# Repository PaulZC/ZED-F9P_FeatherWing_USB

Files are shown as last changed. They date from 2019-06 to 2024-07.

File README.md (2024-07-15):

# ZED-F9P FeatherWing USB

A GNSS FeatherWing incorporating the dual-band (L1 + L2) [u-blox ZED-F9P](https://www.u-blox.com/en/product/zed-f9p-module)

The board can be used stand-alone, powered and interfaced through the USB connector:

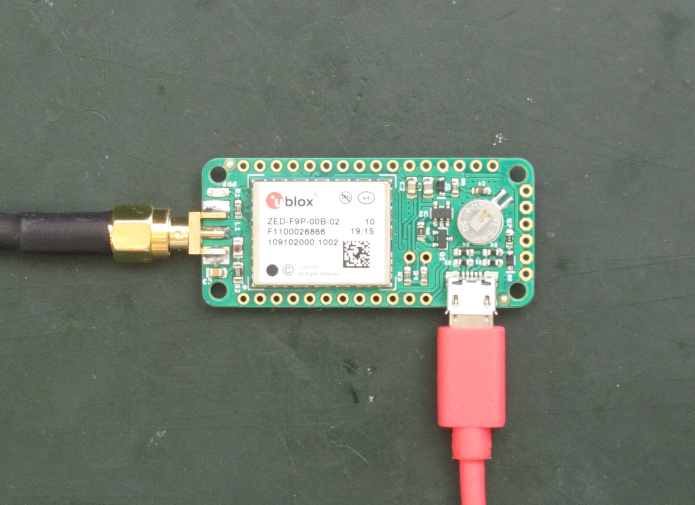
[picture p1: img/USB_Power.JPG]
USB_Power


However, it is designed to mount on top of the [Adafruit Feather M0 Adalogger](https://www.adafruit.com/products/2796)
to form a very compact dual-band PPK data logger or RTK system:

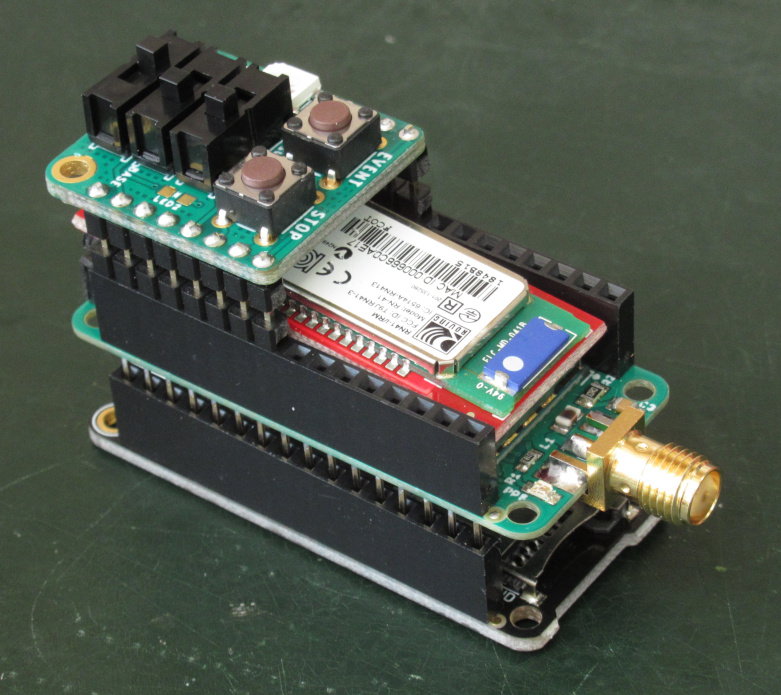
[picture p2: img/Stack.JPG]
Stack


This version provides access to the ZED-F9P's USB port. The [ZED-F9P_FeatherWing](https://github.com/PaulZC/ZED-F9P_FeatherWing) is a simpler version
with fewer components and a CR1220 back-up battery but without USB.

Based extensively on the [Adafruit Ultimate GPS FeatherWing](https://www.adafruit.com/product/3133) and the
[SparkFun GPS-RTK2 Board](https://www.sparkfun.com/products/15136)

If you don't want to make your own FeatherWing and want to use the SparkFun GPS-RTK2 Board instead, you can find a tutorial showing you how to do that
[here](https://github.com/PaulZC/F9P_RAWX_Logger)

See [LEARN.md](./LEARN.md) for more details

[ASSEMBLY.md](./ASSEMBLY.md) contains instructions on how to assemble the PCB

[PAIRING.md](./PAIRING.md) contains instructions on how to configure two SparkFun Bluetooth Mate Gold boards
as a bonded pair, to provide a 115200 Baud RTCM link

The Eagle files are available in the [Eagle folder](./Eagle)

The schematic is available [here](./Schematic.PNG)

The BOM is available [here](./BOM.pdf)

The PCB thickness should be 0.8mm: see the microstrip calculations on the [SparkFun schematic](https://cdn.sparkfun.com/assets/9/a/0/0/a/Qwiic_GPS-RTK2_-_ublox_ZED-F9P.pdf)

## Arduino Code

Two versions of the Arduino code can be found in the [Arduino folder](./Arduino):

- **RAWX_Logger_F9P** is very similar to the logger I wrote for the [NEO-M8T FeatherWing](https://github.com/PaulZC/NEO-M8T_GNSS_FeatherWing) but is substantially updated for the ZED-F9P. It does all of the message configuration via UART1. **PLEASE NOTE:** this example is out-of-date as it uses the old version of the SparkFun u-blox Library.

- **RAWX_Logger_F9P_I2C** uses **version 3.1.5** of the SparkFun u-blox GNSS library to do all of the message configuration via the I2C port instead of UART1. This makes
the code more efficient as it does not need to ignore the UBX ACK messages (on UART1) and can simply stream all data from UART1 to the SD card.

You can find instructions on how to install the Arduino IDE and the required libraries [here](https://github.com/PaulZC/F9P_RAWX_Logger/blob/master/SOFTWARE.md).

The code has three 'modes': Rover, Base and Survey_In. The mode is set via pins A0 and A3 by the [RAWX Logger Switches](https://github.com/PaulZC/RAWX_Logger_Switches). The RAWX
messages are logged to SD card in all three modes for post-processing with [rtklibexplorer's](https://rtklibexplorer.wordpress.com/) version of [RTKLIB](http://rtkexplorer.com/downloads/rtklib-code/).

You will find settings in the code to help with debugging should you need it. Uncomment the line which contains **#define DEBUG** to enable them.

## Updating the ZED-F9P firmware

u-blox released [version 1.12](https://www.u-blox.com/sites/default/files/UBX_F9_100_HPG_112_ZED_F9P.a26bfd58dfd11c233f8fdba6b99adc5a.bin) of the ZED-F9P firmware
on 12th July 2019. If you bought your device(s) before then, it would be beneficial to update. The update process is straight forward and can be done through
the Tools menu in [u-center](https://www.u-blox.com/en/product/u-center) **but the update can only be done through UART1. It will fail if you try to update through USB.**

The [Arduino folder](./Arduino) contains a sketch called ZED-F9P_Echo. This will turn the Adalogger into
a simple USB to UART pass-through which you can use to update the ZED-F9P using u-center. The code runs at **9600 Baud only** so you must tick the
_Use this baudrate for update_ box and select 9600 from the drop-down list. The advice on the u-blox portal seems to be to select the _Use chip erase_ option too.

Updating at 9600 Baud is very slow, but this is the only way to prevent Baud rate changes during the update. The Echo code is very simple and does not support
baud rate changes. If you want to update more quickly, you can use (e.g.) an FTDI TTL-232R-3V3 cable to connect to the UART1 pins instead of the Adalogger.

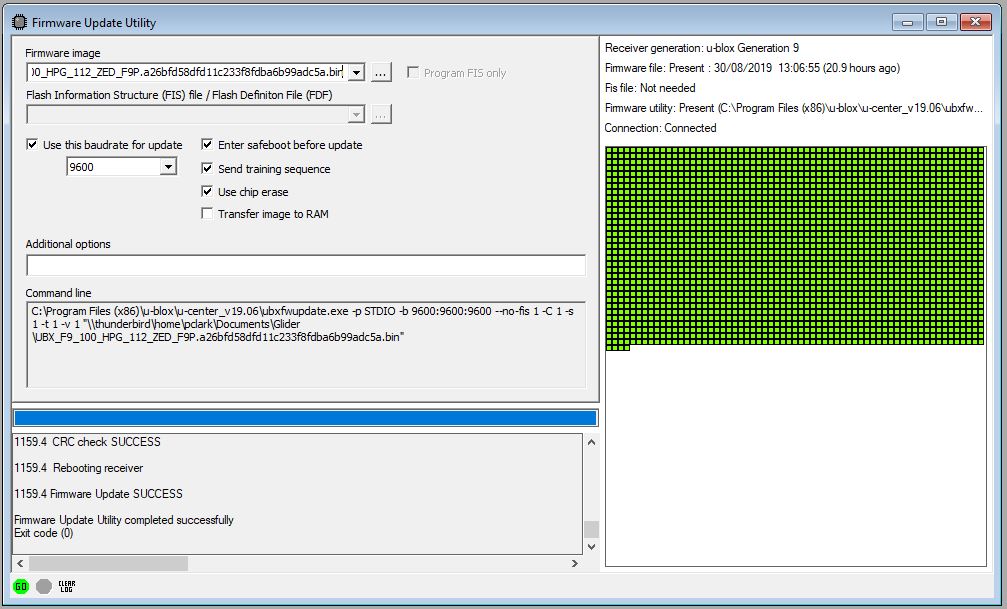
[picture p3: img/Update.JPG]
Update


## Acknowledgements

This project would not have been possible without the open source designs kindly provided by both Adafruit and SparkFun. Their work is gratefully acknowledged.

Adafruit invests time and resources providing this open source design, please support Adafruit and open-source hardware by purchasing products from Adafruit!

Feel like supporting open source hardware? Buy a board from SparkFun!

## Licence

Please see [LICENSE.md](./LICENSE.md) for details.

Enjoy!

**_Paul_**

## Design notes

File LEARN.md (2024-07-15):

# ZED-F9P FeatherWing USB: LEARN

Based extensively on the [Adafruit Ultimate GPS FeatherWing](https://www.adafruit.com/product/3133) and the
[SparkFun GPS-RTK2 Board](https://www.sparkfun.com/products/15136), the ZED-F9P FeatherWing USB takes all the great features of the GPS-RTK2 and squeezes them
into Adafruit FeatherWing format.

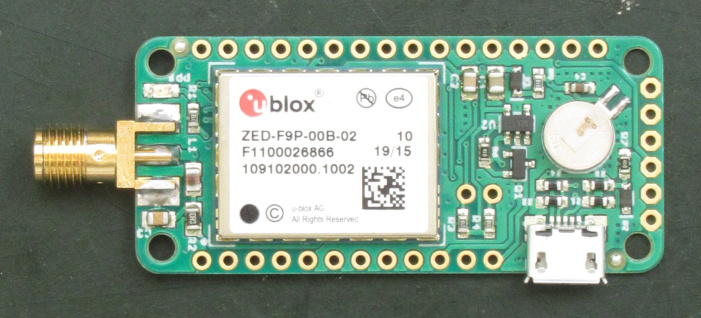
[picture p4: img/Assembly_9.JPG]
Assembly_9


The board can be used stand-alone, powered and interfaced through the USB connector:

USB_Power

However, it is designed to mount on top of the [Adafruit Feather M0 Adalogger](https://www.adafruit.com/products/2796)
to form a very compact dual-band PPK data logger or RTK system, especially when coupled with:
- A [SparkFun Bluetooth Mate Gold](https://www.sparkfun.com/products/12580) to provide the Real Time Correction Message link
- A [RAWX_Logger_Switches board](https://github.com/PaulZC/RAWX_Logger_Switches) to provide on/off, base/rover, survey_in, event and stop-logging buttons plus a NeoPixel for visual feedback

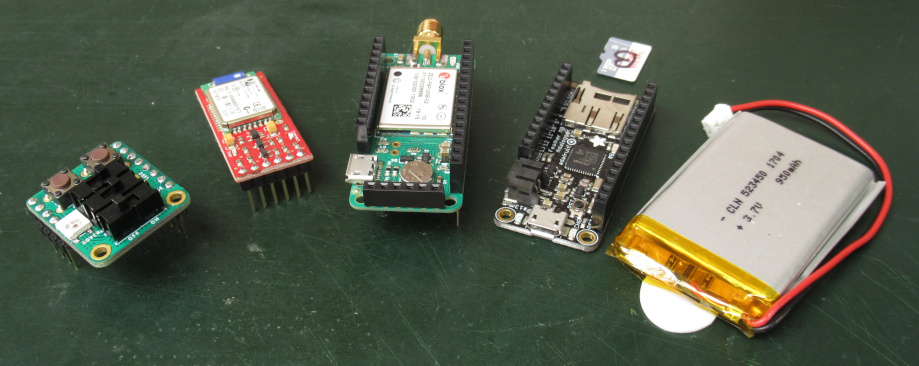
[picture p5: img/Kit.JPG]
Kit


Stack

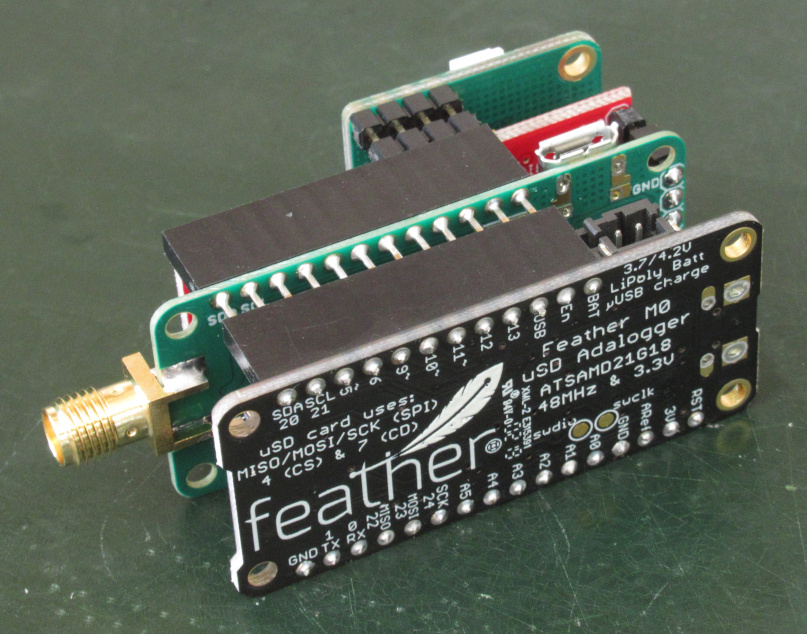
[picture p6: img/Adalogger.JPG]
Adalogger


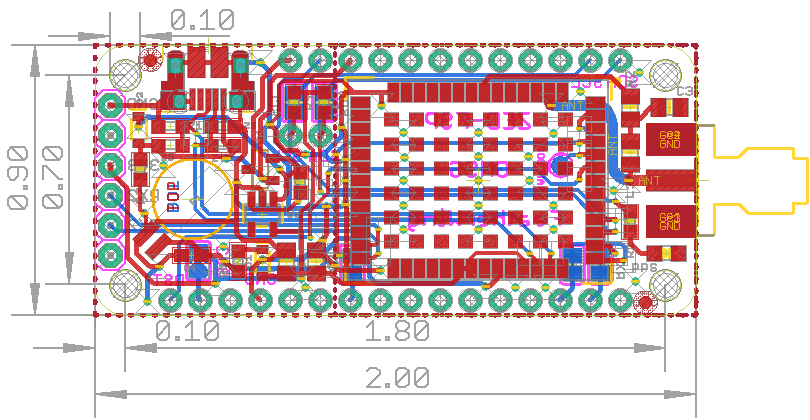
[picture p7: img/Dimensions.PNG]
Dimensions


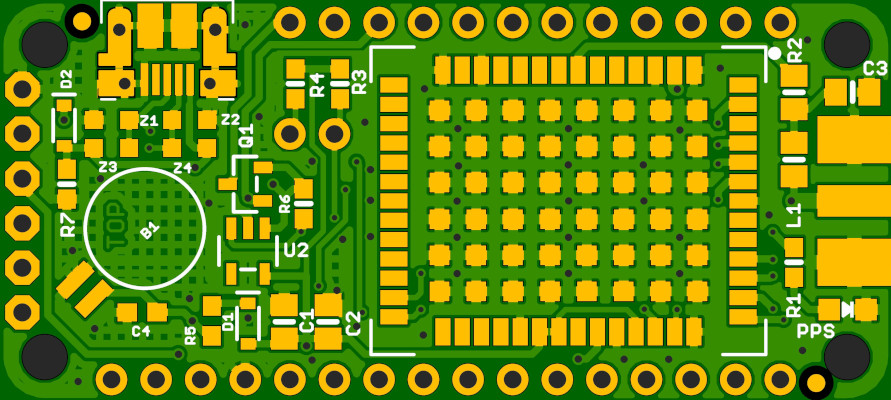
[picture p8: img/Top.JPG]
Top


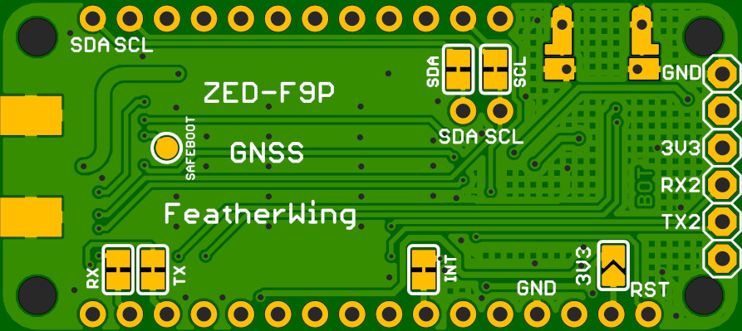
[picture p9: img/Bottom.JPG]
Bottom


### Power Options

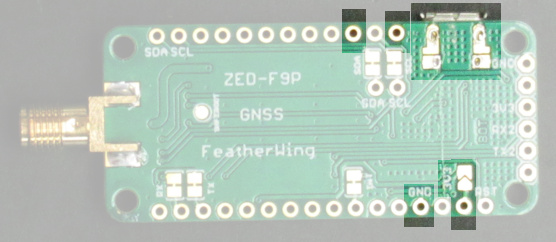
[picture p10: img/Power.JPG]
Power


The FeatherWing can be powered through:
- The micro-USB connector
- The standard FeatherWing LiPo battery and VBUS (USB) pins

The average current draw is approximately 140mA in Survey_In mode when powering the Adalogger, SparkFun Bluetooth Mate Gold and a Taoglas A.80.A.101111 antenna. Select your LiPo battery capacity accordingly!

The board has its own regulator which will regulate battery or USB power down to 3.3V.

The 3V3 pin can be connected by soldering the 3V3 split pad. Only do this if you want to use the pin as a 3.3V output. Don't solder the split pad if you will be mounting the board on a Feather,
the 3.3V regulators will fight each other and bad things may happen!

The power regulator circuit was gratefully plagiarised from the design for the [Adafruit AirLift FeatherWing](https://www.adafruit.com/product/4264).

You can disable the regulator and power down the board by pulling the EN pin low.

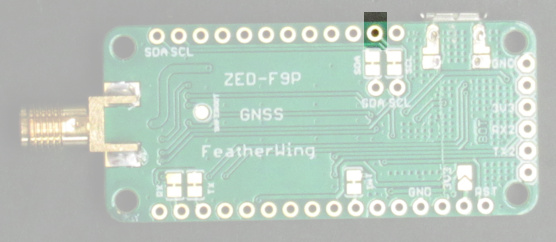
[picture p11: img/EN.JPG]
EN


### USB

The ZED-F9P's USB pins are connected to the micro-USB connector making it easy to talk to the board using [u-center](https://www.u-blox.com/en/product/u-center).

### UART1 Pins

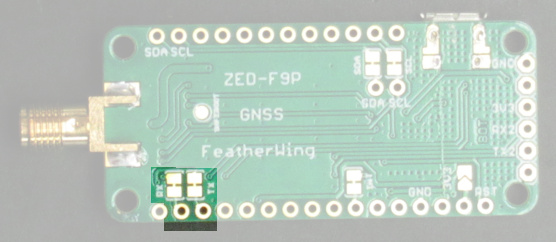
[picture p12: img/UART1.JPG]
UART1


The ZED-F9P's UART1 serial Tx and Rx are connected to the standard Feather Serial1 Rx and Tx pins.

You can isolate the Feather pins if you need to by cutting the TX and RX links.

### UART2 Pins

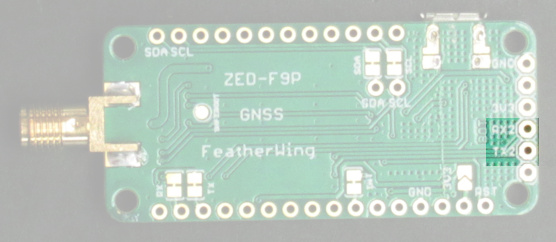
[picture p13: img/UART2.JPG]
UART2


The ZED-F9P's UART2 serial Tx and Rx pins are available on the six pin header on the edge of the board. The pin-out matches the pin-out of the
[SparkFun Bluetooth Mate Gold](https://www.sparkfun.com/products/12580), the Mate can be stacked on top of the board to provide an RTK RTCM link.

### I2C pins

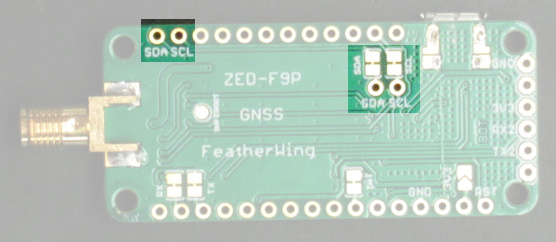
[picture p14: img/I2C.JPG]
I2C


The Zed-F9P's I2C pins are conected to the standard Feather SCL and SDA pins. Pull-up resistors are included (R3 and R4).

You can isolate the Feather pins if you need to by cutting the SDA and SCL links; you can use the extra pins in the center of the board instead.

### SAFEBOOT

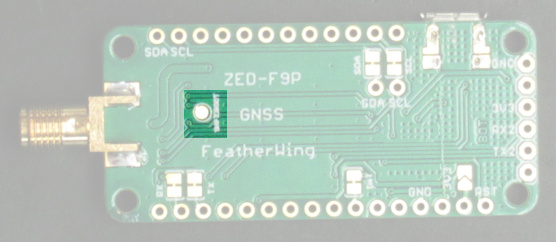
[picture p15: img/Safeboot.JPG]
Safeboot


The ZED-F9P's SAFEBOOT pin is broken out on a test pad on the bottom of the board. You will need access to this if you want to upgrade the ZED-F9P's firmware.

### SPI

Unfortunately, the FeatherWing does not provide access to the ZED-F9P's DSEL pin - there wasn't room! So, you cannot put the ZED-F9P into SPI mode.

### Antenna

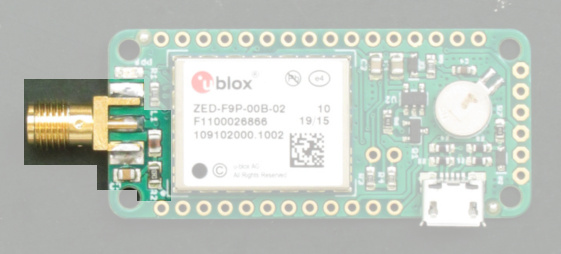
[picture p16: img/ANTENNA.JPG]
ANTENNA


The FeatherWing includes mounting pads for a full size, robust, edge-launch SMA connector. L1, R2 and C3 provide 3.3V power for the required active antenna.

### EXTINT

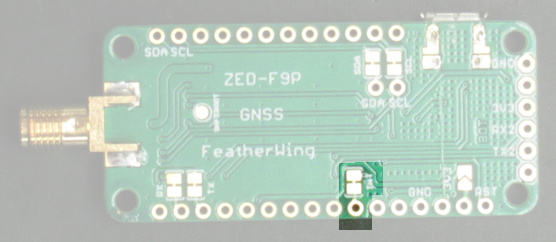
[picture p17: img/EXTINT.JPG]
EXTINT


The ZED-F9P's EXTINT (External Interrupt) pin is linked to the Feather A2 (D16) pin. By pushing the EVENT switch on the RAWX_Logger_Switches board, you can make the ZED-F9P
generate a TIM_TM2 message which can be logged to SD card and extracted with RTKLIB. The RAWX_Logger_F9P code uses A2 as an interrupt to make the NeoPixel on the Switches board flash white.

You can isolate the Feather A2 pin by cutting the INT link.

## Licence

Please see [LICENSE.md](./LICENSE.md) for details.

Enjoy!

**_Paul_**

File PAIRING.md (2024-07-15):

# ZED-F9P FeatherWing USB: Bluetooth Mate Pairing

The ZED-F9P FeatherWing has been designed so that a [SparkFun Bluetooth Mate Gold](https://www.sparkfun.com/products/12580) can be stacked on top of the FeatherWing
to provide a 115200 Baud Real Time Correction Message link.

If you are going to use two FeatherWing systems to form a Base and Rover pair, you will need to pair the Bluetooth Mates with each other so that they automatically
connect to each other on power up (without needing any extra 'connect' commands).

You can find instructions on how to configure the Bluetooth Mate on the [SparkFun website](https://learn.sparkfun.com/tutorials/using-the-bluesmirf/all). I have found that
configuring the Mates as Master and Slave works up to a point, but the Mates don't automatically reconnect after the Slave has been powered off and on again. I have found
that the best solution is to configure them as a bonded pair.

I've tested the following on RN41s programmed with Version 6.15 (04/26/2013) firmware.

You will need to know the MAC ID's of both boards. You can either read this off the sticker on top of the RN41 chip, or use the 'D' command via the serial monitor.
It is a 12 digit hexadecimal number starting with 000666.

You can use the Adalogger as a USB to serial pass-though and configure the boards using the Arduino IDE serial monitor. The
[Arduino folder](./Arduino) contains a sketch called 'Bluetooth_Mate_Echo'. This does the same job as
SparkFun's Passthrough sketch but will also blink the Adalogger's LEDs so you can see the serial port activity.

Connect the Adalogger to the Mate as shown below:

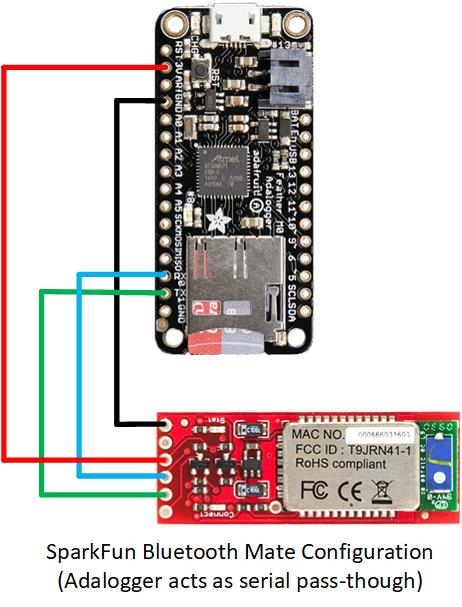
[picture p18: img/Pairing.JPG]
Pairing


and then upload the Bluetooth_Mate_Echo sketch.

- Open the serial monitor, set the Baud rate to **115200** and set the line ending to 'No line ending'
- Type $$$ into the message box and click Send
- You should see the response CMD
- Change the line ending to 'Carriage return'
- Type D into the message box and click Send
- You should see the RN41's settings, including its MAC ID (BTA)
- Enter and send the following commands one at a time:
  - **SX,1** (This enables bonding)
  - **SR,nnnnnnnnnnnn** (where nnnnnnnnnnnn is the MAC ID of the RN41 you want to pair with)
  - **ST,0** (This disables the remote configuration timer)
  - **SA,0** (This disables authentication)
  - **SM,6** (This sets pairing mode)
  - **R,1** (This reboots the RN41)

Repeat this on the other Mate. For the SR command, use the MAC ID of the first mate.

When both Mates are powered up, the green connect LED should light up within a couple of seconds.

If the above does not work correctly and you have changed the settings previously, it might be best to do a factory reset. Enter command mode, send **SF,1** and then **R,1** .
The **SF,1** sets the RN41 back to the factory settings. **R,1** reboots the RN41. Enter command mode again and repeat the above procedure.

Make sure you send the **SX** command _before_ the **SR** command as SX clears any previously stored remote addresses.

You can use the 'D' command to check if the configuration has been changed. You should see 'Mode=Pair', 'Authen=0', 'Bonded=1' and 'Rem=' should be followed by the MAC ID of the paired RN41.

## Acknowledgements

This project would not have been possible without the open source designs and tutorials kindly provided by SparkFun. Their work is gratefully acknowledged.

Feel like supporting open source hardware? Buy a board from SparkFun!

## Licence

Please see [LICENSE.md](./LICENSE.md) for details.

Enjoy!

**_Paul_**

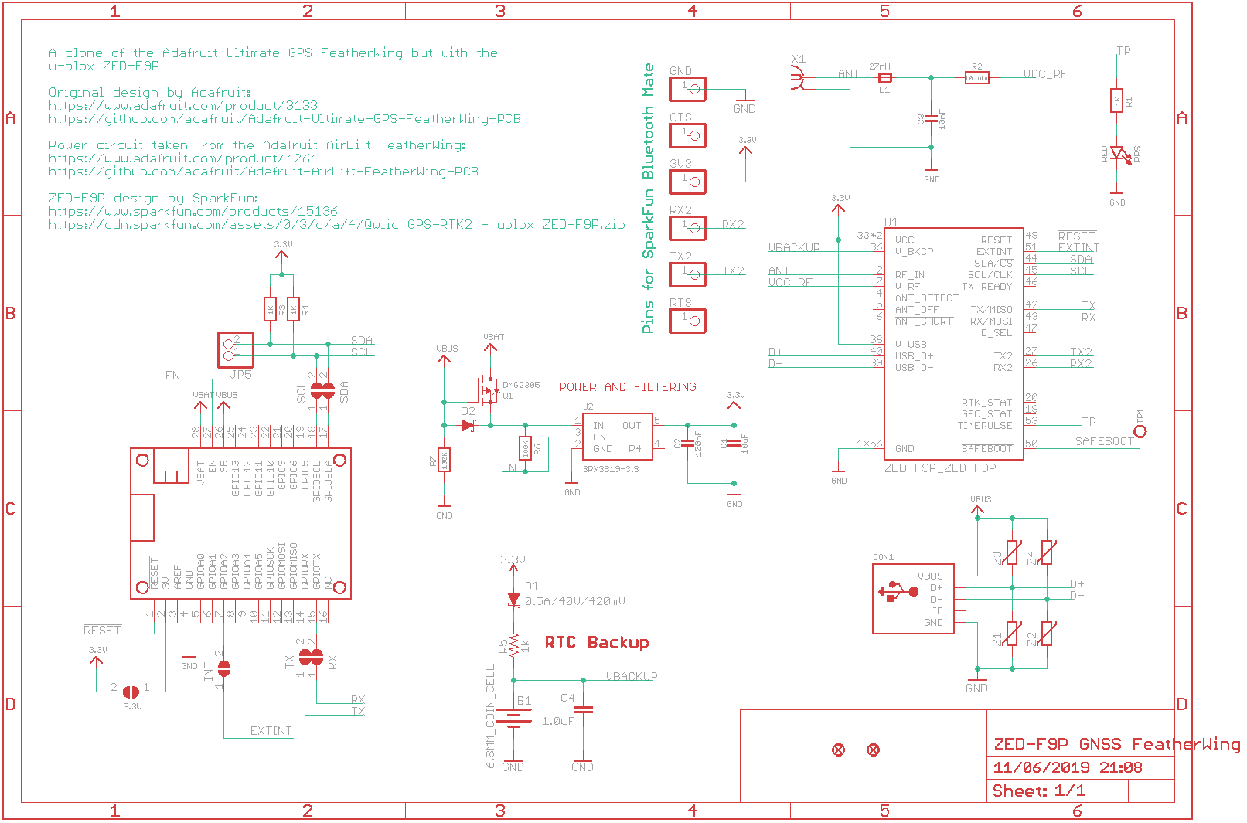
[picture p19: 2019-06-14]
img/Schematic.PNG

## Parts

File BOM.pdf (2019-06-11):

Name | X | Y | Angle | Package | Value | Farnell /
Element 14 Comments
FID1 | 4.67 | 21.65 | 0 | FIDUCIAL
FID2 | 46.51 | 1.06 | 0 | FIDUCIAL
B1 | 4.81 | 6.4 | 225 | MS621FE-FL11E 1614634 | Rechargeable 3V 6.8mm Coin Cell e.g. Seiko MS621FE-FL11E
C1 | 16.2 | 4.54 | 90 | 0805 | 10uF | 2496998 | e.g. Walsin 0805F106Z100CT
C2 | 18.68 | 4.54 | 90 | 0805 | 0.1uF | 2496944 | e.g. Walsin 0805B104K500CT
C3 | 48.58 | 17.62 | 0 | 0805 | 10nF | 2496939 | e.g. Walsin 0805B103K500CT
C4 | 8.1 | 5.08 | 180 | 0603 | 1uF | 2496916 | e.g. Walsin 0603X105K100CT
CON1 | 9.53 | 19.87 | 180 | | Micro_USB | 2293752 | e.g. Amphenol FCI 10103594
D1 | 14.13 | 4.45 | 270 | SOD-323 | PMEG4005EJ | 1757776 | Schottky Rectifier 40V 500mA e.g. Nexperia PMEG4005EJ
D2 | 3.65 | 15.72 | 270 | SOD-323 | PMEG4005EJ | 1757776 | Schottky Rectifier 40V 500mA e.g. Nexperia PMEG4005EJ
L1 | 45.24 | 13.78 | 270 | 0805 | 27nH | 2286463 | e.g. Coilcraft 0805HT-27NTGLB
LED1 | 48.3 | 5.24 | 270 | 2.0x1.25 | RED | 2322077 | e.g. Wurth Electronik 150080RS75000
Q1 | 13.97 | 12.38 | 90 | SOT23 | DMG2305 | 2543532 | Diodes Inc DMG2305UX-13
R1 | 45.24 | 7.93 | 270 | 0603 | 1K | 2447272 | e.g. Multicomp MCWR06X1001FTL
R2 | 45.24 | 17.61 | 90 | 0805 | 10 ohm | 9332421 | e.g. Multicomp MC01W0805110R
R3 | 19.37 | 18.1 | 270 | 0603 | 1K | 2447272 | e.g. Multicomp MCWR06X1001FTL
R4 | 16.83 | 18.1 | 270 | 0603 | 1K | 2447272 | e.g. Multicomp MCWR06X1001FTL
R5 | 12.07 | 4.6 | 90 | 0603 | 1K | 2447272 | e.g. Multicomp MCWR06X1001FTL
R6 | 17.3 | 11.27 | 270 | 0603 | 100K | 2447226 | e.g. Multicomp MCWR06X1003FTL
R7 | 3.81 | 12.38 | 90 | 0603 | 100K | 2447226 | e.g. Multicomp MCWR06X1003FTL
U1 | 32.38 | 11.43 | 180 | ZED-F9P | ZED-F9P | https://www.u-blox.com/en/product/zed-f9p-module
U2 | 14.13 | 8.57 | 180 | SOT23-5 | SPX3819-3.3 | 2889625 | LDO Voltage Regulator 3.3V 500mA e.g. Exar SPX3819M5-L-3-3/TR
X1 | 48.68 | 11.43 | 180 | SMA Jack | | 1019328 | e.g. Johnson 142-0711-821 1019328
Z1 | 6.35 | 16.03 | 180 | 0603 | CG0603MLC-05E 1838966 | 5V ESD Suppressor e.g. Bourns 652-CG0603MLC-05E
Z2 | 10.79 | 16.03 | 0 | 0603 | CG0603MLC-05E 1838966 | 5V ESD Suppressor e.g. Bourns 652-CG0603MLC-05E
Z3 | 6.35 | 14.45 | 0 | 0603 | CG0603MLC-05E 1838966 | 5V ESD Suppressor e.g. Bourns 652-CG0603MLC-05E
Z4 | 10.79 | 14.45 | 180 | 0603 | CG0603MLC-05E 1838966 | 5V ESD Suppressor e.g. Bourns 652-CG0603MLC-05E

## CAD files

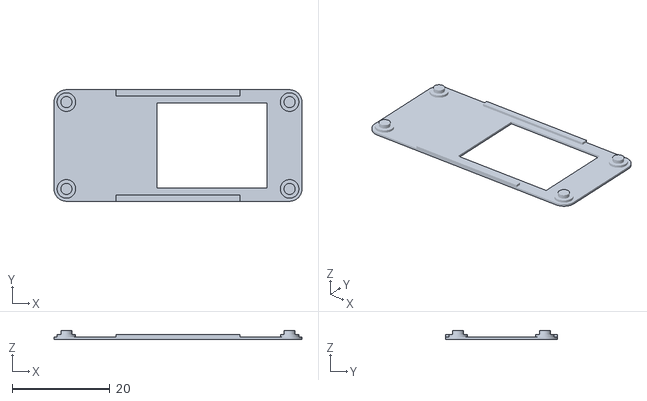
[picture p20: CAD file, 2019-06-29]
OpenSCAD/Zed-F9P_Jig_1.stl
50.8 x 22.9 x 1.75

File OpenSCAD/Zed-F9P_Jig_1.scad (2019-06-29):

// Assembly jig to aid positioning of the ZED-F9P on the FeatherWing

$fn = 90;

// The jig is 2.0" * 0.9"
// Corners are centered on X = 0.1" and 1.9", Y = 0.1" and 0.8"

module base()
{
    union()
    {
            translate([0,0,0])cylinder(r=(0.1*25.4), h=0.5);
            translate([0,(0.7*25.4),0])cylinder(r=(0.1*25.4), h=0.5);
            translate([(1.8*25.4),0,0])cylinder(r=(0.1*25.4), h=0.5);
            translate([(1.8*25.4),(0.7*25.4),0])cylinder(r=(0.1*25.4), h=0.5);
    }
    translate([0,-(0.1*25.4),0])cube([(1.8*25.4),(0.9*25.4),0.5]);
    translate([-(0.1*25.4),0,0])cube([(2.0*25.4),(0.7*25.4),0.5]);
}

module spacers()
{
    union()
    {
        translate([0,0,0])cylinder(r=(0.075*25.4), h=1.0);
        translate([0,(0.7*25.4),0])cylinder(r=(0.075*25.4), h=1.0);
        translate([(1.8*25.4),0,0])cylinder(r=(0.075*25.4), h=1.0);
        translate([(1.8*25.4),(0.7*25.4),0])cylinder(r=(0.075*25.4), h=1.0);
    }
}

module pegs()
{
    union()
    {
        translate([0,0,0])cylinder(r=(0.045*25.4), h=1.75);
        translate([0,(0.7*25.4),0])cylinder(r=(0.045*25.4), h=1.75);
        translate([(1.8*25.4),0,0])cylinder(r=(0.045*25.4), h=1.75);
        translate([(1.8*25.4),(0.7*25.4),0])cylinder(r=(0.045*25.4), h=1.75);
    }
}

module wings()
{
    union()
    {
        translate([(0.9*25.4),(-0.075*25.4),0.5])cube([(1*25.4),(0.05*25.4),1.0],center=true);
        translate([(0.9*25.4),(0.775*25.4),0.5])cube([(1*25.4),(0.05*25.4),1.0],center=true);
    }
}

module hole()
{
    // Cube is taller than it needs to be to avoid zero thickness skins
    translate([32.38,11.43,0])cube([22.5,17.5,2.0],center=true);
}

module jig()
{
    difference()
    {
        translate ([(0.1*25.4),(0.1*25.4),0]) union()
        {
            base();
            spacers();
            pegs();
            wings();
        }
        hole();
    }
}

jig();

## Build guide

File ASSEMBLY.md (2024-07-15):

# ZED-F9P FeatherWing USB Assembly Instructions

Here are the assembly instructions for the ZED-F9P FeatherWing USB:

### Blank PCB

Start by having the blank PCBs manufactured. If you are based in the UK or Europe, I can recommend
[Multi-CB](https://www.multi-circuit-boards.eu/en/index.html) who can manufacture PCBs in 1-8 working days and
can process the Eagle .brd file direct - there's no need to generate Gerber files.

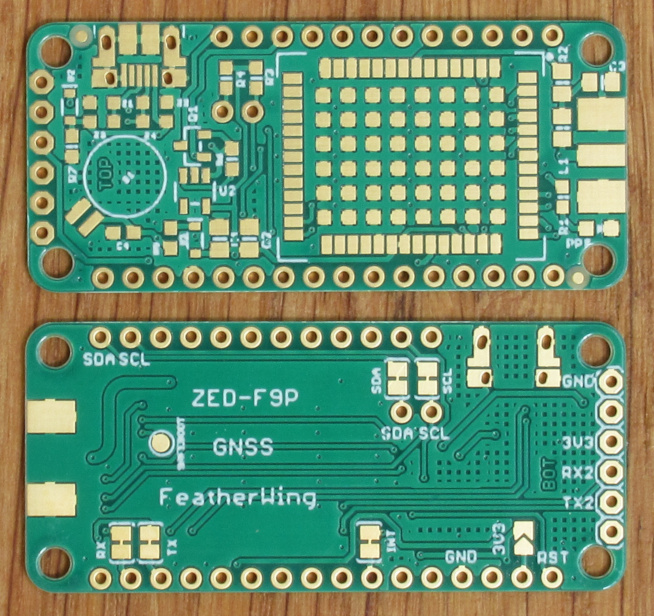
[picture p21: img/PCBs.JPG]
PCBs


My recommended options are:
- Layers: 2 layers
- Format: single pieces
- Surface finish: chemical gold (ENIG)
- Material: FR4, 0.8mm
- Cu layers: 35um
- Solder stop: both sides, green
- Marking print: both sides, white

The 0.8mm PCB thickness is important as it defines the 50 ohm impedance of the antenna traces.

### Add solder paste

Multi-CB can also provide you with a solder paste (SMD) stencil for the PCB. My recommended options are:
- SMD stencil for: top layer
- Make the X and Y dimensions 20mm longer than the PCB itself to allow you to fix it down with tape
- Type: custom
- Pad reduction: yes, 10%
- Thickness: 100um
- Existing fiducials: lasered through
- Text type: half lasered
- Double-sided brushing: yes

I secure the blank PCB onto a flat work surface by locating it between two engineer's squares. I use a sheet of toughened glass
as the work surface as it is both very flat and easy to clean.

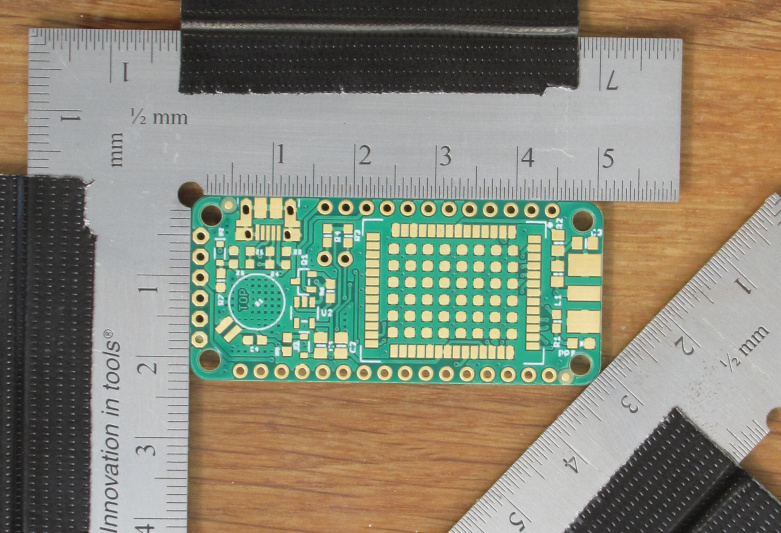
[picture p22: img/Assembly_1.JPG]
Assembly_1


Use the two round fiducials to line up the stencil with the PCB. Secure the stencil with tape.

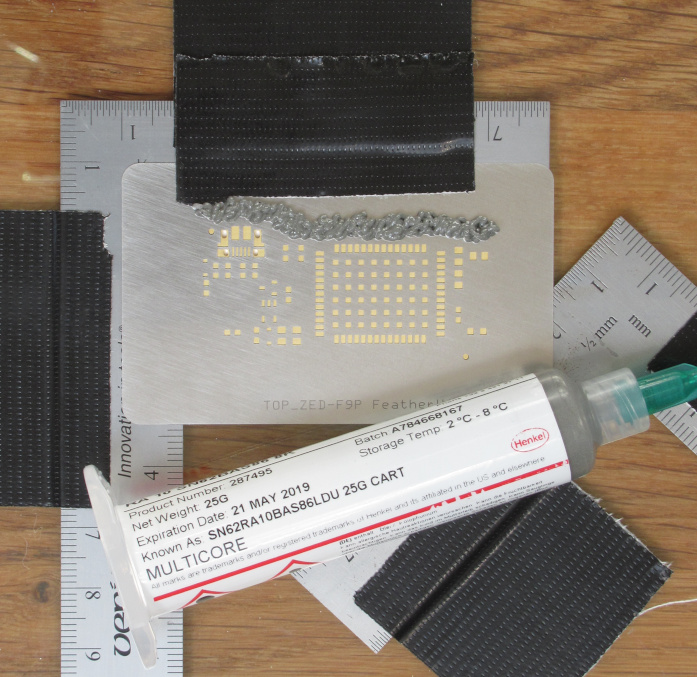
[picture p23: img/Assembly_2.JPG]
Assembly_2


Apply solder paste close to the component cut-outs and then scrape the paste over the stencil using a knife blade or a similar straight edge.
Apply reasonable pressure to keep the stencil held firmly against the circuit board. Try to apply the solder paste in a single pass.
Avoid multiple passes as this will force extra paste into the spaces between the ZED-F9P's pads and could lead to shorts. If in doubt, wash the
paste off with IPA and start again. You need a lot less paste than you might think.

Take appropriate safety precautions when working with solder paste - particularly if you are using tin-lead solder instead of lead-free.

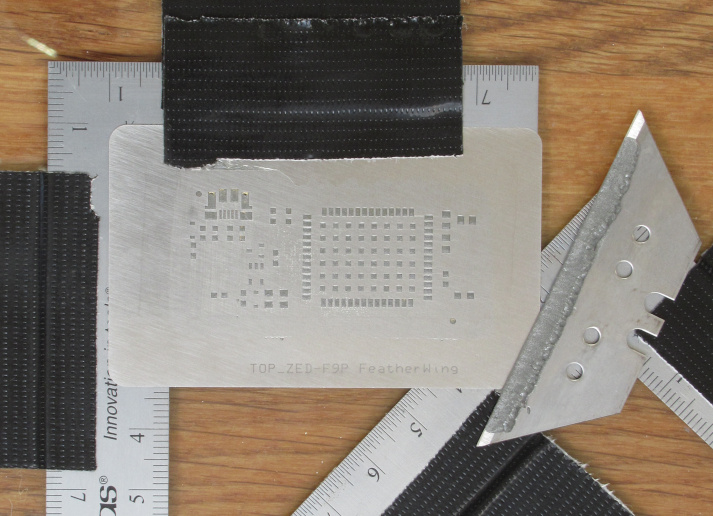
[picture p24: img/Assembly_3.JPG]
Assembly_3


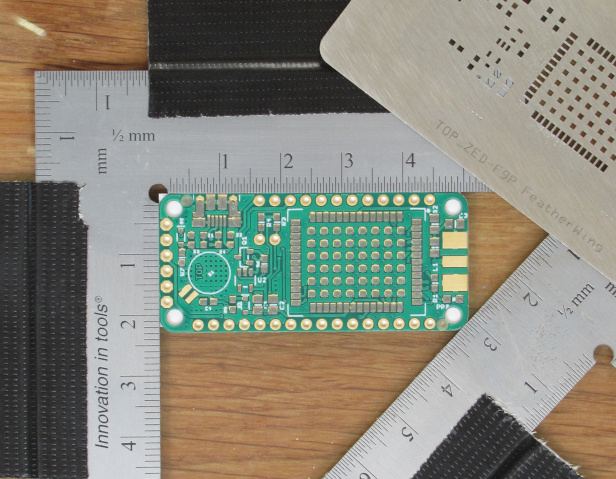
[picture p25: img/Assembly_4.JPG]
Assembly_4


### Position the surface mount components

Position the components onto the blobs of solder paste using tweezers. A magnifier lamp or a USB microscope will
help you place the components in the correct position. You may find the [SMT_Component_Placer](https://github.com/PaulZC/SMT_Component_Placer) useful.

I recommend placing the ZED-F9P first, while the solder paste is fresh. Take extra time when positioning the ZED-F9P. It is an expensive chip and all of the pads are hidden.
Line it up with carefully with the white marks. You will find the OpenSCAD and STL files for a positioning jig in the [OpenSCAD folder](./OpenSCAD).

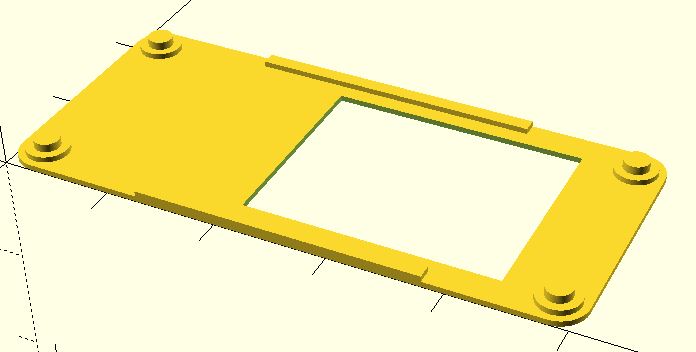
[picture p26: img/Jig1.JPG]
Jig1


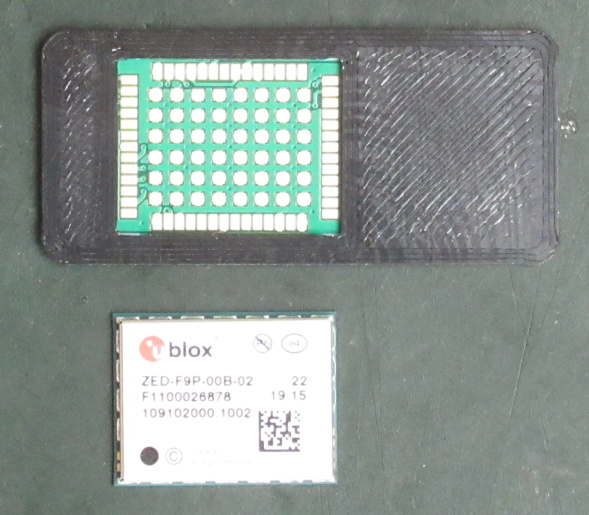
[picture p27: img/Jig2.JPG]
Jig2


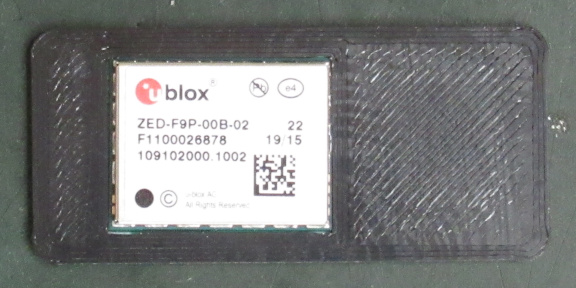
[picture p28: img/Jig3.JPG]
Jig3


**The lithium battery B1 is NOT reflow compatible. You will need to solder it by hand.**

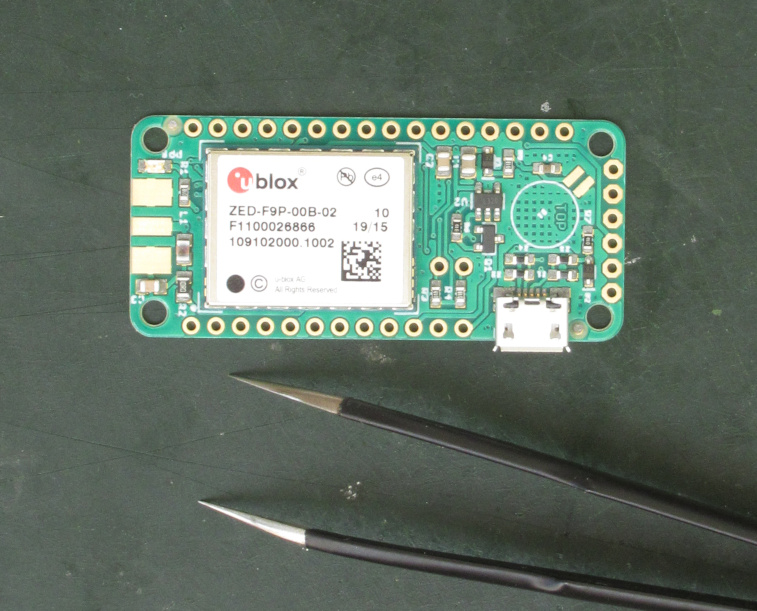
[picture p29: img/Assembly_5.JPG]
Assembly_5


### Reflow the surface mount components

Use a reflow oven to heat the circuit board to the correct temperatures to melt the solder. A reflow oven doesn't need to be
expensive. The one shown below was assembled from:

- Quest 9L 800W mini-oven
- Inkbird PID temperature controller and 40A solid state relay
- Type K thermocouple

Several people have published good reflow oven construction guides, including [this one](http://tt7hab.blogspot.com/2018/06/the-reflow-oven.html) and [this one](http://www.die4laser.com/toaster/index.html).

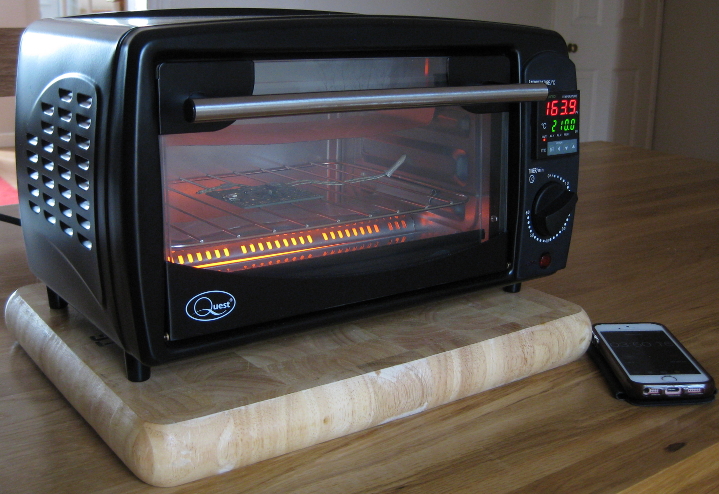
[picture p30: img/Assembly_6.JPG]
Assembly_6


Use the correct temperature profile for your solder paste, but you won't go far wrong with setpoints of 170C for four minutes, followed by
210C for one minute, followed by a cool-down with the door open. Use a flashlight to check that the solder has melted across
the whole PCB at 210C. Hold the temperature at 210C a little longer if some of the solder paste still appears 'gray' instead of 'silver'.

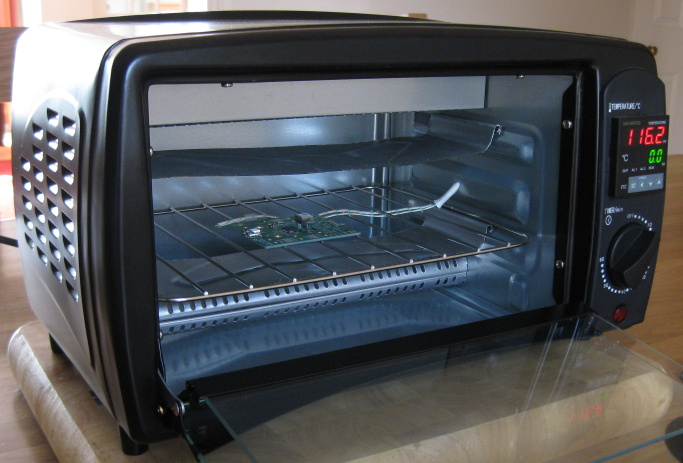
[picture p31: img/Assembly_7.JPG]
Assembly_7


All being well, your PCB should look like this:

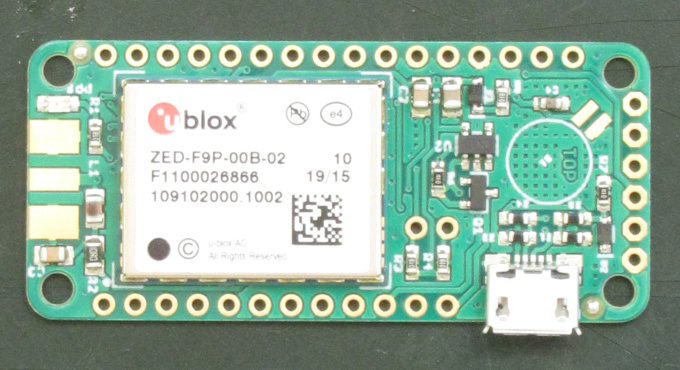
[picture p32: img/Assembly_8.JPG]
Assembly_8


### Check for shorts

Carefully examine all the solder joints and correct any shorts you find.

The 'trick' to removing a short is to add more solder or solder paste and then to use copper solder braid or wick to remove all the solder in one go.
Use good quality braid and make sure it comes pre-coated with flux. Some cheap braids don't have flux on them and don't work anywhere near as well.

Use a cotton swab dipped in Iso-Propyl Alcohol (IPA / Propanol / rubbing alcohol) to remove any flux residue.

### Add the non-surface mount components

The non-surface mount components (rechargeable battery and SMA connector) can now be soldered in by hand.

Assembly_9

The board can be used stand-alone and powered through the USB connector. However, it is designed to mount on top of the [Adafruit Feather M0 Adalogger](https://www.adafruit.com/products/2796)
and [stacking headers](https://www.adafruit.com/product/2830) are ideal for that.

If you are going to use a [SparkFun Bluetooth Mate Gold](https://www.sparkfun.com/products/12580) to provide the Real Time Correction link, you might also want to add a cut-down (6-way) piece of
[short header](https://www.adafruit.com/product/2940).

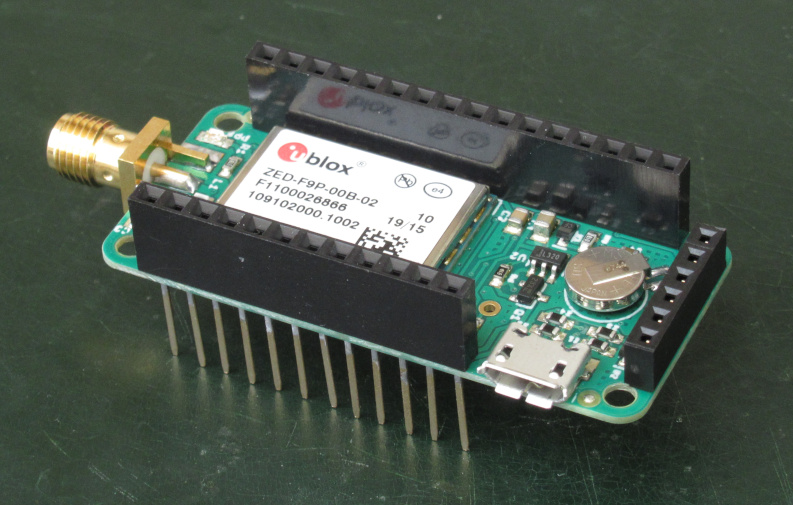
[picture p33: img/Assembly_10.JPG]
Assembly_10


### Lacquer the PCB

I recommend giving the PCB a coat of lacquer, especially if you are intending to use it on a UAV. Cover all of the surface mount components with
[Acrylic Protective Lacquer (conformal coating)](https://uk.rs-online.com/web/p/conformal-coatings/3217324/) except the connectors and IO pads.

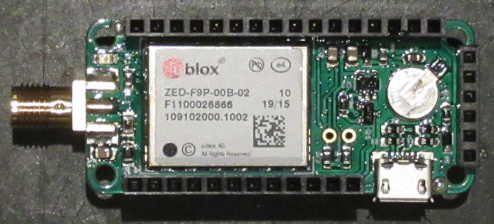
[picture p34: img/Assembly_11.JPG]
Assembly_11


## Licence

Please see [LICENSE.md](./LICENSE.md) for details.

Enjoy!

**_Paul_**

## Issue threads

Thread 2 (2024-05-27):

Ubx file with more than 60minutes

bugalaws, 2024-05-27:
Hi Paul , can tou help me? What change i have to do to write a ubx file with more than 60 minutes?

I did see this line:
const int INTERVAL = 15;

And there say it higher value is 60 minutes… but if i need to write a log with a 3hours for example… can you help me?

PaulZC, 2024-05-28:
Hi @bugalaws ,

The code in this repo is out of date. Please see: https://github.com/PaulZC/ZED-F9P_FeatherWing_USB?tab=readme-ov-file#arduino-code . It uses the SAMD21G18A TimerCounter3 to set the logging duration. You would need to change the code in many places to make it log for 3 hours.

It is possible to join the 15 minute files together into one file:

```
In Windows:
- Copy the UBX files from the SD card into a normal Documents folder
- Open a cmd prompt (type cmd into the search box on the toolbar and hit enter)
- cd (change directory) into the Documents folder
- Use the following command to concatenate all the UBX files (b_HHMMSS.ubx) into a single file
- copy /b b_*.ubx base.ubx

In Linux:
- cat b_*.ubx > base.ubx
```

I hope this helps,
Paul

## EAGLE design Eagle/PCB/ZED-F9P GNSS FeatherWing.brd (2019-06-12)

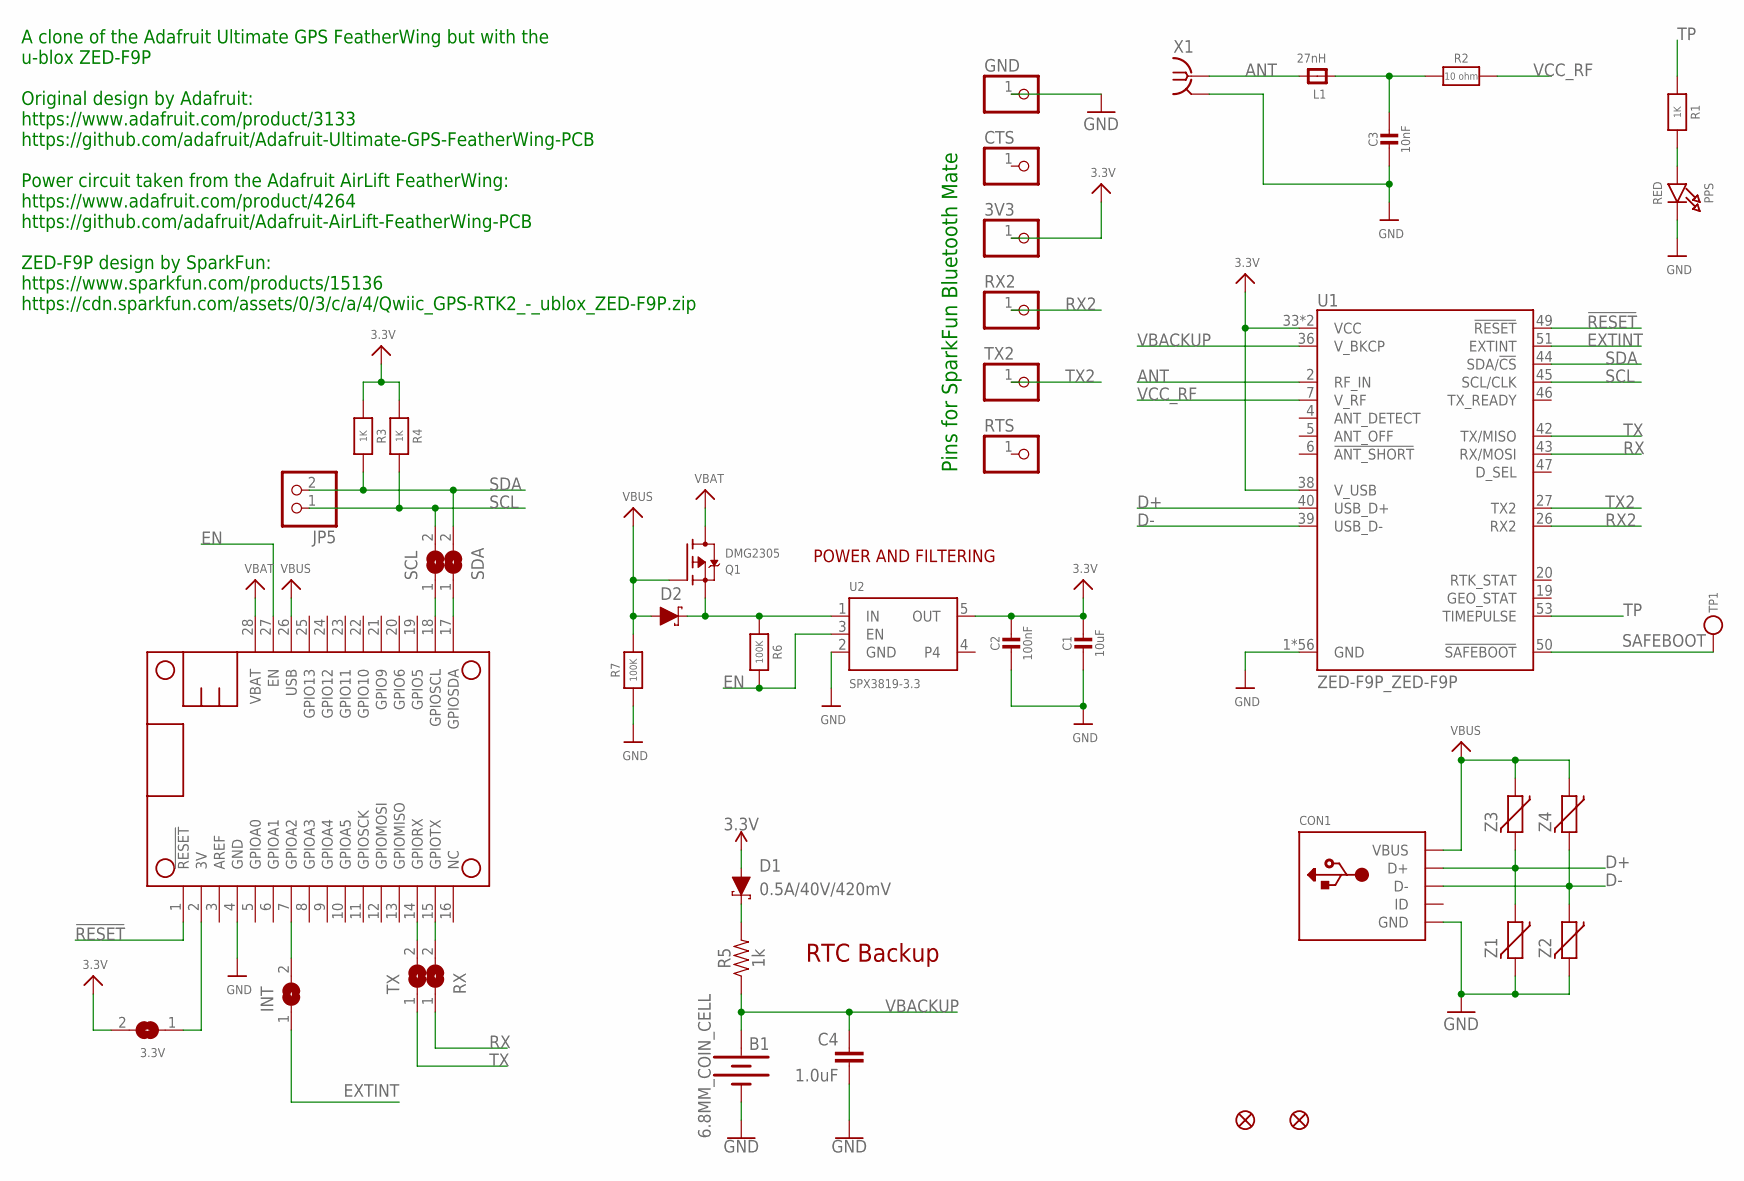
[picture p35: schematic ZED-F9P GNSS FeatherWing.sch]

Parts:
3.3V: SOLDERJUMPER; SOLDERJUMPER_ARROW_NOPASTE
3V3: PINHD-1X1; 1X01
B1: 6.8MM_COIN_CELL; BATTCON-6.8MM
C1: 10uF; 0805-NO
C2: 100nF; 0805-NO
C3: 10nF; 0805-NO
C4: 1.0uF; 0603
CON1: MICROBUILDER_USBFCI_10103594_CORRECTED; MICROBUILDER_FCI_10103594_CORRECTED
CTS: PINHD-1X1; 1X01
D1, D2: 0.5A/40V/420mV; SOD-323
FID1, FID2: FIDUCIAL""; FIDUCIAL_1MM
GND: PINHD-1X1; 1X01
INT: SOLDERJUMPERCLOSED; SOLDERJUMPER_CLOSEDWIRE
JP5: HEADER-1X2ROUND; 1X02_ROUND
L1: 27nH; 0805-NO
MS1: MICROBUILDER_FEATHERWINGMICROBUILDER_FEATHERWING_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; MICROBUILDER_FEATHERWING_HOLES
PPS: RED; CHIPLED_0805_NOOUTLINE
Q1: DMG2305; SOT23-R
R1, R3, R4: 1K; 0603-NO
R2: 10 ohm; 0805-NO
R5: 1k; 0603
R6, R7: 100K; 0603-NO
RTS: PINHD-1X1; 1X01
RX: SOLDERJUMPERCLOSED; SOLDERJUMPER_CLOSEDWIRE
RX2: PINHD-1X1; 1X01
SCL: SOLDERJUMPERCLOSED; SOLDERJUMPER_CLOSEDWIRE
SDA: SOLDERJUMPERCLOSED; SOLDERJUMPER_CLOSEDWIRE
TP1: TESTPOINTROUND1.5MM; TESTPOINT_ROUND_1.5MM
TX: SOLDERJUMPERCLOSED; SOLDERJUMPER_CLOSEDWIRE
TX2: PINHD-1X1; 1X01
U1: ZED-F9P_ZED-F9P
U2: SPX3819-3.3; SOT23-5
X1: SMA-142-0711-821/826; J502-ND-142-0711-821/826
Z1, Z2, Z3, Z4: CG0603MLC-05E; CT/CN0603

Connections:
3.3V: 3.3V.2, 3V3.1, C1.1, C2.1, D1.A, R3.1, R4.1, U1.33 (VCC), U1.34 (VCC), U1.38 (V_USB), U2.5 (OUT)
3V: 3.3V.1, MS1.2 (3V)
!RESET: MS1.1 (!RESET), U1.49 (!RESET!)
ANT: L1.2, U1.2 (RF_IN), X1.1
D+: CON1.D+, U1.40 (USB_D+), Z1.1, Z3.2
D-: CON1.D-, U1.39 (USB_D-), Z2.1, Z4.2
EN: MS1.27 (EN), R6.2, U2.3 (EN)
EXTINT: INT.1, U1.51 (EXTINT)
GND: B1.-, C1.2, C2.2, C3.2, C4.2, CON1.BASE@1 (GND), CON1.BASE@2 (GND), CON1.GND, CON1.SPRT@1 (GND), CON1.SPRT@2 (GND), CON1.SPRT@3 (GND), CON1.SPRT@4 (GND), GND.1, MS1.4 (GND), PPS.C, R7.1, U1.1 (GND), U1.3 (GND), U1.12 (GND), U1.14 (GND), U1.32 (GND), U1.37 (GND), U1.41 (GND), U1.48 (GND), U1.55 (GND), U1.56 (GND), U1.57 (GND), U1.58 (GND), U1.59 (GND), U1.60 (GND), U1.61 (GND), U1.62 (GND), U1.63 (GND), U1.64 (GND), U1.65 (GND), U1.66 (GND), U1.67 (GND), U1.68 (GND), U1.69 (GND), U1.70 (GND), U1.71 (GND), U1.72 (GND), U1.73 (GND), U1.74 (GND), U1.75 (GND), U1.76 (GND), U1.77 (GND), U1.78 (GND), U1.79 (GND), U1.80 (GND), U1.81 (GND), U1.82 (GND), U1.83 (GND), U1.84 (GND), U1.85 (GND), U1.86 (GND), U1.87 (GND), U1.88 (GND), U1.89 (GND), U1.90 (GND), U1.91 (GND), U1.92 (GND), U1.93 (GND), U1.94 (GND), U1.95 (GND), U1.96 (GND), U1.97 (GND), U1.98 (GND), U1.99 (GND), U1.100 (GND), U1.101 (GND), U1.102 (GND), U2.2 (GND), X1.G@1 (2), X1.G@2 (2), X1.G@3 (2), X1.G@4 (2), Z1.2, Z2.2
unnamed: MS1.18 (GPIOSCL), SCL.1
unnamed: PPS.A, R1.2
unnamed: MS1.17 (GPIOSDA), SDA.1
unnamed: C3.1, L1.1, R2.1
unnamed: MS1.14 (GPIORX), TX.2
unnamed: MS1.15 (GPIOTX), RX.2
unnamed: INT.2, MS1.7 (GPIOA2)
unnamed: D1.C, R5.2
unnamed: D2.C, Q1.2 (S), R6.1, U2.1 (IN)
RX: RX.1, U1.43 (RX/MOSI)
RX2: RX2.1, U1.26 (RX2)
SAFEBOOT: TP1.P$1, U1.50 (!SAFEBOOT!)
SCL: JP5.1, R4.2, SCL.2, U1.45 (SCL/CLK)
SDA: JP5.2, R3.2, SDA.2, U1.44 (SDA/!CS!)
TP: R1.1, U1.53 (TIMEPULSE)
TX: TX.1, U1.42 (TX/MISO)
TX2: TX2.1, U1.27 (TX2)
VBACKUP: B1.+, C4.1, R5.1, U1.36 (V_BKCP)
VBAT: MS1.28 (VBAT), Q1.3 (D)
VBUS: CON1.VBUS, D2.A, MS1.26 (USB), Q1.1 (G), R7.2, Z3.1, Z4.1
VCC_RF: R2.2, U1.7 (V_RF)

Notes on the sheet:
A clone of the Adafruit Ultimate GPS FeatherWing but with the u-blox ZED-F9P Original design by Adafruit: https://www.adafruit.com/product/3133 https://github.com/adafruit/Adafruit-Ultimate-GPS-FeatherWing-PCB Power circuit taken from the Adafruit AirLift FeatherWing: https://www.adafruit.com/produ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
Pins for SparkFun Bluetooth Mate
RTC Backup
POWER AND FILTERING

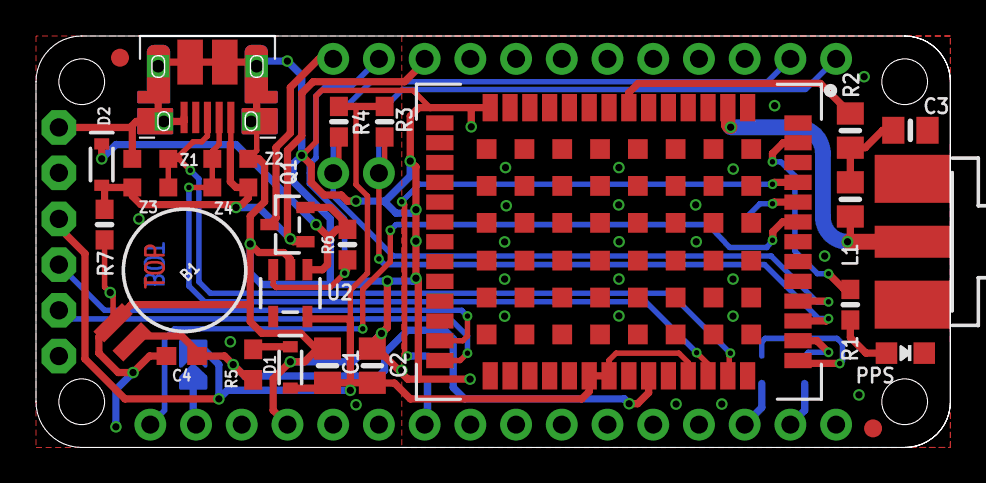
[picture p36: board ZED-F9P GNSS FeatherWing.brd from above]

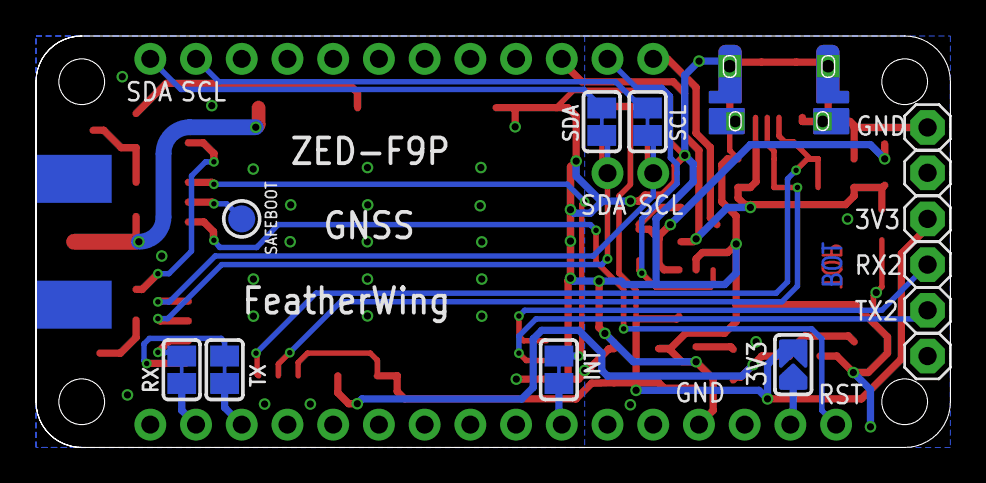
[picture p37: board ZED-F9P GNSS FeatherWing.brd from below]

Board: 2 copper layers, 50.8 x 22.9 mm, 42 parts (13 on the bottom side), 30 nets.

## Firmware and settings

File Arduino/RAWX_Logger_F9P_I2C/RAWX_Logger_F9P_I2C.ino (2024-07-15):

// RAWX_Logger_F9P_I2C

// Change Log:
// ===========
//
// July 15th 2024:
// ===============
// Updated for:
// Adafruit SAMD Boards (1.7.16) :   http://boardsmanager/All#Adafruit_SAMD_Boards
// SparkFun u-blox GNSS v3 (3.1.5) : http://librarymanager/All#SparkFun_u-blox_GNSS_v3
// Bill Greiman's SdFat (2.2.3) :    http://librarymanager/All#SdFat
// RTCZero (1.6.0) :                 http://librarymanager/All#RTCZero
// Adafruit Neopixel (1.12.3) :      http://librarymanager/All#Adafruit_NeoPixel
//
// Changes the RTC alarm code to match on HHMMSS - allowing longer log INTERVAL (up to 24 hours)
// Updates the UBX configuration functions to use addCfgValset and the values from u-blox_config_keys.h
// Corrects sd.begin
// Default to logging at 1Hz, not 4Hz
// Works with exFAT microSD

// Logs RXM-RAWX, RXM-SFRBX and TIM-TM2 data from u-blox ZED_F9P GNSS to SD card
// Also logs NAV_PVT messages (which provide the carrSoln status) and NAV-STATUS messages (which indicate a time fix for Survey_In mode)
// Also logs high precision NMEA GNGGA position solution messages which can be extracted by RTKLIB

// This code is written for the Adalogger M0 Feather
// ** Select "Adafruit Feather M0" as the board type **
// ** Set Optimize to "Fast" **
// https://www.adafruit.com/products/2796
// https://learn.adafruit.com/adafruit-feather-m0-adalogger
// Adafruit invests time and resources providing this open source design, please support Adafruit and open-source hardware by purchasing products from Adafruit!

// GNSS data is provided by the ZED-F9P FeatherWing
// ** For best results, update the ZED-F9P firmware to v1.32 **
// https://github.com/PaulZC/ZED-F9P_FeatherWing_USB

// This version uses **version 3.1.5** the SparkFun u-blox library to configure the RAWX messages via I2C,
// leaving the UART dedicated for the messages to be logged to SD card
// Feel like supporting open source hardware? Buy a board from SparkFun!
// ZED-F9P RTK2: https://www.sparkfun.com/products/15136

// Choose a good quality SD card. Some cheap cards can't handle the write rate.

// Open a new log file every INTERVAL minutes

// Define how long we should log in minutes before changing to a new file
// Sensible values are: 5, 10, 15, 20, 30, 60, etc.
// Max is 1440 (24 Hours)
const int INTERVAL = 60;

// Define how long we should wait in msec (approx.) for residual RAWX data before closing the last log file
// For a measurement rate of 1Hz (1000msec), 1100msec is a sensible value. i.e. slightly more than one measurement interval
const int dwell = 1100;

// Send serial debug messages
//#define DEBUG // Comment this line out to disable debug messages
//#define DEBUGi2c // Comment this line out to disable I2C debug messages

// Debug SerialBuffer
// Displays a "Max bufAvail:" message each time SerialBuffer.available reaches a new maximum
//#define DEBUGserialBuffer // Comment this to disable serial buffer maximum available debugging

// Connect modePin to GND to select base mode. Leave open for rover mode.
#define modePin 14 // A0 / Digital Pin 14

// Connect a normally-open push-to-close switch between swPin and GND.
// Press it to stop logging and close the log file.
#define swPin 15 // A1 / Digital Pin 15 (0.2" away from the GND pin on the Adalogger)

// Pin A2 (Digital Pin 16) is reserved for the ZED-F9P EXTINT signal
// The code uses this an an interrupt to set the NeoPixel to white
#define ExtIntPin 16 // A2 / Digital Pin 16
#define white_flash 1000 // Flash the NeoPxel white for this many milliseconds on every ExtInt

// Connect A3 (Digital Pin 17) to GND to select SURVEY_IN mode when in BASE mode
#define SurveyInPin 17 // A3 / Digital Pin 17

// Include the SparkFun u-blox Library
#include <Wire.h> //Needed for I2C to GPS
#include <SparkFun_u-blox_GNSS_v3.h> //http://librarymanager/All#SparkFun_u-blox_GNSS_v3
SFE_UBLOX_GNSS i2cGPS;

// LEDs

//#define NoLED // Uncomment this line to completely disable the LEDs
//#define NoLogLED // Uncomment this line to disable the LEDs during logging only

// NeoPixel Settings
#define NeoPixel // Uncomment this line to enable a NeoPixel on the same pin as RedLED

// The red LED flashes during SD card writes
#define RedLED 13 // The red LED on the Adalogger is connected to Digital Pin 13
// The green LED indicates that the GNSS has established a fix 
#define GreenLED 8 // The green LED on the Adalogger is connected to Digital Pin 8

// Include the Adafruit NeoPixel Library
#ifdef NeoPixel
#include <Adafruit_NeoPixel.h> // Support for the WB2812B
#define swap_red_green // Uncomment this line if your WB2812B has red and green reversed
#ifdef swap_red_green
  Adafruit_NeoPixel pixels = Adafruit_NeoPixel(1, RedLED, NEO_GRB + NEO_KHZ800); // GRB WB2812B
#else
  Adafruit_NeoPixel pixels = Adafruit_NeoPixel(1, RedLED, NEO_RGB + NEO_KHZ800); // RGB WB2812B
#endif
#define LED_Brightness 32 // 0 - 255 for WB2812B
#endif

// Fast SD card logging using Bill Greiman's SdFat
// https://github.com/greiman/SdFat
// From FatFile.h:
//   * \note Data is moved to the cache but may not be written to the
//   * storage device until sync() is called.

#include <SPI.h>
#include <SdFat.h>
const uint8_t cardSelect = 4; // Adalogger uses D4 as the SD SPI select
SdFat sd;
SdFile rawx_dataFile;
// The log filename starts with "r_" for the rover and "b_" for the static base
bool base_mode = true; // Flag to indicate if the code is in base or rover mode
char rawx_filename[] = "20000000/b_000000.ubx"; // the b will be replaced by an r if required
char dirname[] = "20000000";
long bytes_written = 0;

bool survey_in_mode = false; // Flag to indicate if the code is in survey_in mode

// Timer to indicate if an ExtInt has been received
volatile unsigned long ExtIntTimer; // Load this with millis plus white_flash to show when the ExtInt LED should be switched off

// Define packet size, buffer and buffer pointer for SD card writes
const size_t SDpacket = 512;
uint8_t serBuffer[SDpacket];
size_t bufferPointer = 0;
int numBytes;

// Battery voltage
float vbat;
#define LOWBAT 3.55 // Low battery voltage

// Include Real Time Clock support for the M0
// https://github.com/arduino-libraries/RTCZero
#include <RTCZero.h> // M0 Real Time Clock
RTCZero rtc; // Create an rtc object
volatile bool alarmFlag = false; // RTC alarm (interrupt) flag

// Count number of valid fixes before starting to log
#define maxvalfix 10 // Collect at least this many valid fixes before logging starts
int valfix = 0;

bool stop_pressed = false; // Flag to indicate if stop switch was pressed to stop logging

// Define SerialBuffer as a large RingBuffer which we will use to store the Serial1 receive data
// Actual Serial1 receive data will be copied into SerialBuffer by a timer interrupt
// https://gist.github.com/jdneo/43be30d85080b175cb5aed3500d3f989
// That way, we do not need to increase the size of the Serial1 receive buffer (by editing RingBuffer.h)
// You can use DEBUGserialBuffer to determine how big the buffer should be. Increase it if you see bufAvail get close to or reach the buffer size.
RingBufferN<16384> SerialBuffer; // Define SerialBuffer as a RingBuffer of size 16k bytes

// Loop Steps
#define init          0
#define start_rawx    1
#define open_file     2
#define write_file    3
#define new_file      4
#define close_file    5
#define restart_file  6
int loop_step = init;

// UBX and NMEA Parse State
#define looking_for_B5_dollar   0
#define looking_for_62          1
#define looking_for_class       2
#define looking_for_ID          3
#define looking_for_length_LSB  4
#define looking_for_length_MSB  5
#define processing_payload      6
#define looking_for_checksum_A  7
#define looking_for_checksum_B  8
#define sync_lost               9
#define looking_for_asterix     10
#define looking_for_csum1       11
#define looking_for_csum2       12
#define looking_for_term1       13
#define looking_for_term2       14
int ubx_nmea_state = looking_for_B5_dollar;
int ubx_length = 0;
int ubx_class = 0;
int ubx_ID = 0;
int ubx_checksum_A = 0;
int ubx_checksum_B = 0;
int ubx_expected_checksum_A = 0;
int ubx_expected_checksum_B = 0;
int nmea_char_1 = '0'; // e.g. G
int nmea_char_2 = '0'; // e.g. P
int nmea_char_3 = '0'; // e.g. G
int nmea_char_4 = '0'; // e.g. G
int nmea_char_5 = '0'; // e.g. A
int nmea_csum = 0;
int nmea_csum1 = '0';
int nmea_csum2 = '0';
int nmea_expected_csum1 = '0';
int nmea_expected_csum2 = '0';
#define max_nmea_len 100 // Maximum length for an NMEA message: use this to detect if we have lost sync while receiving an NMEA message

// Definitions for u-blox F9P UBX-format (binary) messages

// Disable NMEA output on the I2C port
bool disableI2cNMEA() {
  bool result = i2cGPS.newCfgValset(VAL_LAYER_RAM);
  result &= i2cGPS.addCfgValset(UBLOX_CFG_I2COUTPROT_NMEA, 0);
  result &= i2cGPS.sendCfgValset();
  return result;
}

// Set UART1 to 230400 Baud
bool setUART1BAUD() {
  bool result = i2cGPS.newCfgValset(VAL_LAYER_RAM);
  result &= i2cGPS.addCfgValset(UBLOX_CFG_UART1_BAUDRATE, 230400);
  result &= i2cGPS.sendCfgValset();
  return result;
}

// setRAWXoff: this is the message which disables all of the messages being logged to SD card
// It also clears the NMEA high precision mode for the GPGGA message
// It also sets the main talker ID to 'GP'
bool setRAWXoff() {
  bool result = i2cGPS.newCfgValset(VAL_LAYER_RAM);
  result &= i2cGPS.addCfgValset(UBLOX_CFG_MSGOUT_UBX_RXM_RAWX_UART1, 0);
  result &= i2cGPS.addCfgValset(UBLOX_CFG_MSGOUT_UBX_RXM_SFRBX_UART1, 0);
  result &= i2cGPS.addCfgValset(UBLOX_CFG_MSGOUT_UBX_TIM_TM2_UART1, 0);
  result &= i2cGPS.addCfgValset(UBLOX_CFG_MSGOUT_UBX_NAV_POSLLH_UART1, 0);
  result &= i2cGPS.addCfgValset(UBLOX_CFG_MSGOUT_UBX_NAV_PVT_UART1, 0);
  result &= i2cGPS.addCfgValset(UBLOX_CFG_MSGOUT_UBX_NAV_STATUS_UART1, 0);
  result &= i2cGPS.addCfgValset(UBLOX_CFG_NMEA_MAINTALKERID, UBX_NMEA_MAINTALKERID_GP);
  result &= i2cGPS.addCfgValset(UBLOX_CFG_NMEA_HIGHPREC, 0);
  result &= i2cGPS.addCfgValset(UBLOX_CFG_MSGOUT_NMEA_ID_GGA_UART1, 0);
  result &= i2cGPS.sendCfgValset();
  return result;
}

// setRAWXon: this is the message which enables all of the messages to be logged to SD card in one go
// It also sets the NMEA high precision mode for the GNGGA message
// It also sets the main talker ID to 'GN'
bool setRAWXon() {
  bool result = i2cGPS.newCfgValset(VAL_LAYER_RAM);
  result &= i2cGPS.addCfgValset(UBLOX_CFG_MSGOUT_UBX_RXM_RAWX_UART1, 1);
  result &= i2cGPS.addCfgValset(UBLOX_CFG_MSGOUT_UBX_RXM_SFRBX_UART1, 1);
  result &= i2cGPS.addCfgValset(UBLOX_CFG_MSGOUT_UBX_TIM_TM2_UART1, 1);
  result &= i2cGPS.addCfgValset(UBLOX_CFG_MSGOUT_UBX_NAV_POSLLH_UART1, 0);
  result &= i2cGPS.addCfgValset(UBLOX_CFG_MSGOUT_UBX_NAV_PVT_UART1, 1);
  result &= i2cGPS.addCfgValset(UBLOX_CFG_MSGOUT_UBX_NAV_STATUS_UART1, 1);
  result &= i2cGPS.addCfgValset(UBLOX_CFG_NMEA_MAINTALKERID, UBX_NMEA_MAINTALKERID_GN);
  result &= i2cGPS.addCfgValset(UBLOX_CFG_NMEA_HIGHPREC, 1);
  result &= i2cGPS.addCfgValset(UBLOX_CFG_MSGOUT_NMEA_ID_GGA_UART1, 1);
  result &= i2cGPS.sendCfgValset();
  return result;
}

// Enable the NMEA GGA and RMC messages on UART1
bool setNMEAon() {
  bool result = i2cGPS.newCfgValset(VAL_LAYER_RAM);
  result &= i2cGPS.addCfgValset(UBLOX_CFG_MSGOUT_NMEA_ID_GLL_UART1, 0);
  result &= i2cGPS.addCfgValset(UBLOX_CFG_MSGOUT_NMEA_ID_GSA_UART1, 0);
  result &= i2cGPS.addCfgValset(UBLOX_CFG_MSGOUT_NMEA_ID_GSV_UART1, 0);
  result &= i2cGPS.addCfgValset(UBLOX_CFG_MSGOUT_NMEA_ID_VTG_UART1, 0);
  result &= i2cGPS.addCfgValset(UBLOX_CFG_INFMSG_NMEA_UART1, 0);
  result &= i2cGPS.addCfgValset(UBLOX_CFG_MSGOUT_NMEA_ID_GGA_UART1, 1);
  result &= i2cGPS.addCfgValset(UBLOX_CFG_MSGOUT_NMEA_ID_RMC_UART1, 1);
  result &= i2cGPS.sendCfgValset();
  return result;
}

// Disable the NMEA messages
bool setNMEAoff() {
  bool result = i2cGPS.newCfgValset(VAL_LAYER_RAM);
  result &= i2cGPS.addCfgValset(UBLOX_CFG_MSGOUT_NMEA_ID_GLL_UART1, 0);
  result &= i2cGPS.addCfgValset(UBLOX_CFG_MSGOUT_NMEA_ID_GSA_UART1, 0);
  result &= i2cGPS.addCfgValset(UBLOX_CFG_MSGOUT_NMEA_ID_GSV_UART1, 0);
  result &= i2cGPS.addCfgValset(UBLOX_CFG_MSGOUT_NMEA_ID_VTG_UART1, 0);
  result &= i2cGPS.addCfgValset(UBLOX_CFG_INFMSG_NMEA_UART1, 0);
  result &= i2cGPS.addCfgValset(UBLOX_CFG_MSGOUT_NMEA_ID_GGA_UART1, 0);
  result &= i2cGPS.addCfgValset(UBLOX_CFG_MSGOUT_NMEA_ID_RMC_UART1, 0);
  result &= i2cGPS.sendCfgValset();
  return result;
}

// Set the Main NMEA Talker ID to "GP"
bool setTALKERID() {
  bool result = i2cGPS.newCfgValset(VAL_LAYER_RAM);
  result &= i2cGPS.addCfgValset(UBLOX_CFG_NMEA_MAINTALKERID, UBX_NMEA_MAINTALKERID_GP);
  result &= i2cGPS.sendCfgValset();
  return result;
}

// Set the measurement rate (actually interval in ms)
bool setRATE(uint16_t interval) {
  bool result = i2cGPS.newCfgValset(VAL_LAYER_RAM);
  result &= i2cGPS.addCfgValset(UBLOX_CFG_RATE_MEAS, interval);
  result &= i2cGPS.sendCfgValset();
  return result;
}
bool setRATE_20Hz() { return setRATE(50); }
bool setRATE_10Hz() { return setRATE(100); }
bool setRATE_5Hz() { return setRATE(200); }
bool setRATE_4Hz() { return setRATE(250); }
bool setRATE_2Hz() { return setRATE(500); }
bool setRATE_1Hz() { return setRATE(1000); }

// Set the navigation dynamic model
bool setNAV(uint8_t model) {
  bool result = i2cGPS.newCfgValset(VAL_LAYER_RAM);
  result &= i2cGPS.addCfgValset(UBLOX_CFG_NAVSPG_DYNMODEL, model);
  result &= i2cGPS.sendCfgValset();
  return result;
}
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
void loop() // run over and over again
{
  switch(loop_step) {
    case init: {

      static uint8_t hour = 0;
      static uint8_t min = 0;
      static uint8_t sec = 0;
      static uint16_t msec = 0;
      static uint8_t day = 0;
      static uint8_t month = 0;
      static uint16_t year = 0;
      static uint8_t fix = 0;
      static int32_t lat = 0;
      static int32_t lon = 0;
      static int32_t alt = 0;
      static int32_t speed = 0;
      static int32_t heading = 0;
      static uint16_t pdop = 0;
      static uint8_t siv = 0;

      if (i2cGPS.getPVT()) { // Poll PVT. Returns true when new data is received
        hour = i2cGPS.getHour();
        min = i2cGPS.getMinute();
        sec = i2cGPS.getSecond();
        msec = i2cGPS.getMillisecond();
        day = i2cGPS.getDay();
        month = i2cGPS.getMonth();
        year = i2cGPS.getYear();
        fix = i2cGPS.getFixType();
        lat = i2cGPS.getLatitude();
        lon = i2cGPS.getLongitude();
        alt = i2cGPS.getAltitude();
        speed = i2cGPS.getGroundSpeed();
        heading = i2cGPS.getHeading();
        pdop = i2cGPS.getPDOP();
        siv = i2cGPS.getSIV();
      }

#ifdef DEBUG
      Serial.print("\nTime: ");
      Serial.print(hour, DEC); Serial.print(':');
      Serial.print(min, DEC); Serial.print(':');
      Serial.print(sec, DEC); Serial.print('.');
      Serial.println(msec);
      Serial.print("Date: ");
      Serial.print(day, DEC); Serial.print('/');
      Serial.print(month, DEC); Serial.print("/");
      Serial.println(year, DEC);
      Serial.print("Fix: "); Serial.println(fix);
      if (fix > 0) {
        Serial.print("Location: ");
        float latitude = ((float)lat) / 10000000.0;
        Serial.print(F("Lat: "));
        Serial.print(latitude, 6);
        float longitude = ((float)lon) / 10000000.0;
        Serial.print(F(" Lon: "));
        Serial.print(longitude, 6);
        Serial.print(F(" (degrees)"));
        float altitude = ((float)alt) / 1000.0;
        Serial.print(F(" Alt: "));
        Serial.print(altitude, 2);
        Serial.println(F(" (m)"));

        float speed_f = ((float)speed) / 1000.0;
        Serial.print("Ground Speed (m/s): "); Serial.println(speed_f, 3);
        float heading_f = ((float)heading) / 10000000.0;
        Serial.print("Heading: "); Serial.println(heading_f, 1);
        Serial.print("Satellites: "); Serial.println(siv);
        float PDOP = ((float)pdop) / 100.0;
        Serial.print("PDOP: "); Serial.println(PDOP, 2);
      }
#endif
  
      // read battery voltage
      vbat = analogRead(A7) * (2.0 * 3.3 / 1023.0);
#ifdef DEBUG
      Serial.print("Battery(V): ");
      Serial.println(vbat, 2);
#endif
    
      // turn green LED on to indicate GNSS fix
      // or set NeoPixel to cyan
      if (fix >= 3) {
#ifndef NoLED
#ifdef NeoPixel
        setLED(cyan); // Set NeoPixel to cyan
#else
        digitalWrite(GreenLED, HIGH);
#endif
#endif
        // increment valfix and cap at maxvalfix
        // don't do anything fancy in terms of decrementing valfix as we want to keep logging even if the fix is lost
        valfix += 1;
        if (valfix > maxvalfix) valfix = maxvalfix;
      }
      else {
#ifndef NoLED
#ifdef NeoPixel
        setLED(dim_cyan); // Set NeoPixel to dim cyan
#else
        digitalWrite(GreenLED, LOW); // Turn green LED off
#endif
#endif
      }

      if (valfix == maxvalfix) { // wait until we have enough valid fixes

        // Set and start the RTC
        alarmFlag = false; // Make sure alarm flag is clear
        rtc.begin(); // Start the RTC
        rtc.setTime(hour, min, sec); // Set the time
        rtc.setDate(day, month, (uint8_t)(year - 2000)); // Set the date
        delay(1100); // Wait for 1s in case interval is 1440
        uint8_t nextAlarmHour = hour;
        uint16_t interval = INTERVAL; // Get the INTERVAL
        if (interval >= 1440) // Limit the interval to 24 hours
          interval = 0; // An interval of zero produces an alarm every 24 hours
        uint16_t nextAlarmMin = ((uint16_t)min) + interval; // Add on the INTERVAL
        while (nextAlarmMin >= 60) { // Increment the hour
          nextAlarmMin -= 60;
          nextAlarmHour++;
        }
        nextAlarmHour %= 24; // Day rollover
        rtc.setAlarmTime(nextAlarmHour, nextAlarmMin, sec); // Set the alarm time
        rtc.enableAlarm(rtc.MATCH_HHMMSS); // Alarm Match on hours, minutes and seconds
        rtc.attachInterrupt(alarmMatch); // Attach alarm interrupt

        // check if voltage is > LOWBAT(V), if not then don't try to log any data
        if (vbat < LOWBAT) {
          Serial.println("Low Battery!");
          break;
        }

        // Set the RAWX measurement rate
        //setRATE_20Hz(); // Set Navigation/Measurement Rate to 20 Hz
        //setRATE_10Hz(); // Set Navigation/Measurement Rate to 10 Hz
        //setRATE_5Hz(); // Set Navigation/Measurement Rate to 5 Hz
        //setRATE_4Hz(); // Set Navigation/Measurement Rate to 4 Hz
        //setRATE_2Hz(); // Set Navigation/Measurement Rate to 2 Hz
        setRATE_1Hz(); // Set Navigation/Measurement Rate to 1 Hz
        
        // If we are in BASE mode, check the SURVEY_IN pin
        if (base_mode == true) {
          if (digitalRead(SurveyInPin) == LOW) {
            // We are in BASE mode and the SURVEY_IN pin is low so send the extra UBX messages:
            Serial.println("SURVEY_IN mode selected");
            survey_in_mode = true; // Set the survey_in_mode flag true
            setRTCMon(); // Enable the RTCM messages on UART2
            delay(1100);
            setSurveyIn(); // Enable SURVEY_IN mode
            delay(1100);
          }
        }
        
        while(Serial1.available()){Serial1.read();} // Flush RX buffer to clear any old data

        // Now that Serial1 should be idle and the buffer empty, start TC3 interrupts to copy all new data into SerialBuffer
        // Set the timer interval to 10 * 10 / 230400 = 0.000434 secs (10 bytes * 10 bits (1 start, 8 data, 1 stop) at 230400 baud)
        startTimerInterval(0.000434); 
        
        loop_step = start_rawx; // start rawx messages
      }
    }
    break;

    // (Re)Start RAWX messages
    case start_rawx: {
      setRAWXon(); // (Re)Start the UBX and NMEA messages

      bufferPointer = 0; // (Re)initialise bufferPointer

      loop_step = open_file; // start logging rawx data
    }
    break;

    // Open the log file
    case open_file: {
      
      // Get the RTC time and date
      uint8_t RTCseconds = rtc.getSeconds();
      uint8_t RTCminutes = rtc.getMinutes();
      uint8_t RTChours = rtc.getHours();
      uint8_t RTCday = rtc.getDay();
      uint8_t RTCmonth = rtc.getMonth();
      uint8_t RTCyear = rtc.getYear();
      
      // Do the divides to convert date and time to char
      char secT = RTCseconds/10 + '0';
      char secU = RTCseconds%10 + '0';
      char minT = RTCminutes/10 + '0';
      char minU = RTCminutes%10 + '0';
      char hourT = RTChours/10 + '0';
      char hourU = RTChours%10 + '0';
      char dayT = RTCday/10 +'0';
      char dayU = RTCday%10 +'0';
      char monT = RTCmonth/10 +'0';
      char monU = RTCmonth%10 +'0';
      char yearT = RTCyear/10 +'0';
      char yearU = RTCyear%10 +'0';
  
      // filename is limited to 8.3 characters so use format: YYYYMMDD/b_HHMMSS.ubx or YYYYMMDD/r_HHMMSS.ubx
      rawx_filename[2] = yearT;
      rawx_filename[3] = yearU;
      rawx_filename[4] = monT;
      rawx_filename[5] = monU;
      rawx_filename[6] = dayT;
      rawx_filename[7] = dayU;
      if (base_mode == false) rawx_filename[9] = 'r';
      rawx_filename[11] = hourT;
      rawx_filename[12] = hourU;
      rawx_filename[13] = minT;
      rawx_filename[14] = minU;
      rawx_filename[15] = secT;
      rawx_filename[16] = secU;
      
      dirname[2] = yearT;
      dirname[3] = yearU;
      dirname[4] = monT;
      dirname[5] = monU;
      dirname[6] = dayT;
      dirname[7] = dayU;


      // flash red LED to indicate SD write (leave on if an error occurs)
      // or flash NeoPixel green
#ifndef NoLED
#ifdef NeoPixel
#ifndef NoLogLED
      setLED(green); // Set the NeoPixel to green
#else
      setLED(black); // Turn NeoPixel off if NoLogLED
#endif
#else
#ifndef NoLogLED
      digitalWrite(RedLED, HIGH); // Turn the red LED on to indicate SD card write
#else
      digitalWrite(RedLED, LOW); // Turn the red LED off for NoLogLED
      digitalWrite(GreenLED, LOW); // Turn the green LED off for NoLogLED
#endif
#endif
#endif
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

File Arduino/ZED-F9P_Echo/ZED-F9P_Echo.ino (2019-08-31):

// ZED-F9P Echo

// Simple serial echo for the u-blox ZED-F9P to help with firmware updates

// ** Changes the ZED-F9P Baud rate from 38400 to 9600 **

// Designed to run on the Adafruit Feather M0 Adalogger
// https://www.adafruit.com/product/2796
// https://learn.adafruit.com/adafruit-feather-m0-adalogger

// Code is based on:
// https://github.com/adafruit/Adafruit_GPS/tree/master/examples/GPS_HardwareSerial_EchoTest

// Set UART1 to 9600 Baud
// UBX-CFG-VALSET message with a key ID of 0x40520001 (CFG-UART1-BAUDRATE) and a value of 0x00002580 (9600 decimal)
static const uint8_t setUART1BAUD[] = { 0xb5, 0x62,  0x06, 0x8a,  0x0c, 0x00,  0x00, 0x01, 0x00, 0x00,  0x01, 0x00, 0x52, 0x40,  0x80, 0x25, 0x00, 0x00 };
static const int len_setUART1BAUD = 18;

// Send message in u-blox UBX format
// Calculates and appends the two checksum bytes
// Doesn't add the 0xb5 and 0x62 sync chars (these need to be included at the start of the message)
void sendUBX(const uint8_t *message, const int len) {
  int csum1 = 0; // Checksum bytes
  int csum2 = 0;
  for (int i=0; i<len; i++) { // For each byte in the message
    Serial1.write(message[i]); // Write the byte
    if (i >= 2) { // Don't include the sync chars in the checksum
      csum1 = csum1 + message[i]; // Update the checksum bytes
      csum2 = csum2 + csum1;
    }
  }
  csum1 = csum1 & 0xff; // Limit checksums to 8-bits
  csum2 = csum2 & 0xff;
  Serial1.write((uint8_t)csum1); // Send the checksum bytes
  Serial1.write((uint8_t)csum2);
}

void setup()
{
  pinMode(13, OUTPUT); // Red LED
  digitalWrite(13, LOW);
  pinMode(8, OUTPUT); // Green LED
  digitalWrite(8, LOW);

  // Give the ZED-F9P time to power up
  delay(2000);

  Serial1.begin(38400); // Start off using 38400 Baud to talk to the ZED-F9P

  // Change the ZED-F9P UART Baud rate
  sendUBX(setUART1BAUD, len_setUART1BAUD); // Set ZED-F9P UART1 baud rate to 9600

  // Allow time for Baud rate change
  delay(1000);

  // Restart serial communications at 9600 Baud
  Serial1.begin(9600);
}
     
void loop() // run over and over again
{
  if (Serial.available()) {
    digitalWrite(13, HIGH); // Flash red LED
    char c = Serial.read();
    Serial1.write(c);
    digitalWrite(13, LOW);
  }
  if (Serial1.available()) {
    digitalWrite(8, HIGH); // Flash green LED
    char c = Serial1.read();
    Serial.write(c);
    digitalWrite(8, LOW);
  }  
}

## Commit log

2019-06-11 Updated the power circuit
    [ZED-F9P FeatherWing Paste.brd, ZED-F9P GNSS FeatherWing.brd, ZED-F9P GNSS FeatherWing.sch]
2019-06-12 Ready for manufacture
    [ZED-F9P GNSS FeatherWing.brd, ZED-F9P GNSS FeatherWing.sch]
2019-06-29 Added PAIRING info, placement jig and more images
    [Zed-F9P_Jig_1.scad, Zed-F9P_Jig_1.stl]
2019-06-30 Updated the solder paste instructions
2019-06-30 Added Assembly_11.JPG
2019-08-31 Firmware update. New I2C RAWX Logger.
    Added details of how to update the ZED-F9P firmware using ZED-F9P_Echo.
    Updated the I2C RAWX Logger code to use the new setVal functions in version 1.6 of the SparkFun u-blox library.
2019-08-31 Update RAWX_Logger_F9P_I2C.ino
    The I2C RAWX Logger now uses the SparkFun u-blox library to set the RTC. The Adafruit GPS library is no longer needed.
    [RAWX_Logger_F9P_I2C.ino]
2019-11-08 Code can now 'disable' the timepulse LED

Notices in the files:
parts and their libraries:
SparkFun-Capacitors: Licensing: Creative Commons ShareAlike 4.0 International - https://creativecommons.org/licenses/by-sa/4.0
